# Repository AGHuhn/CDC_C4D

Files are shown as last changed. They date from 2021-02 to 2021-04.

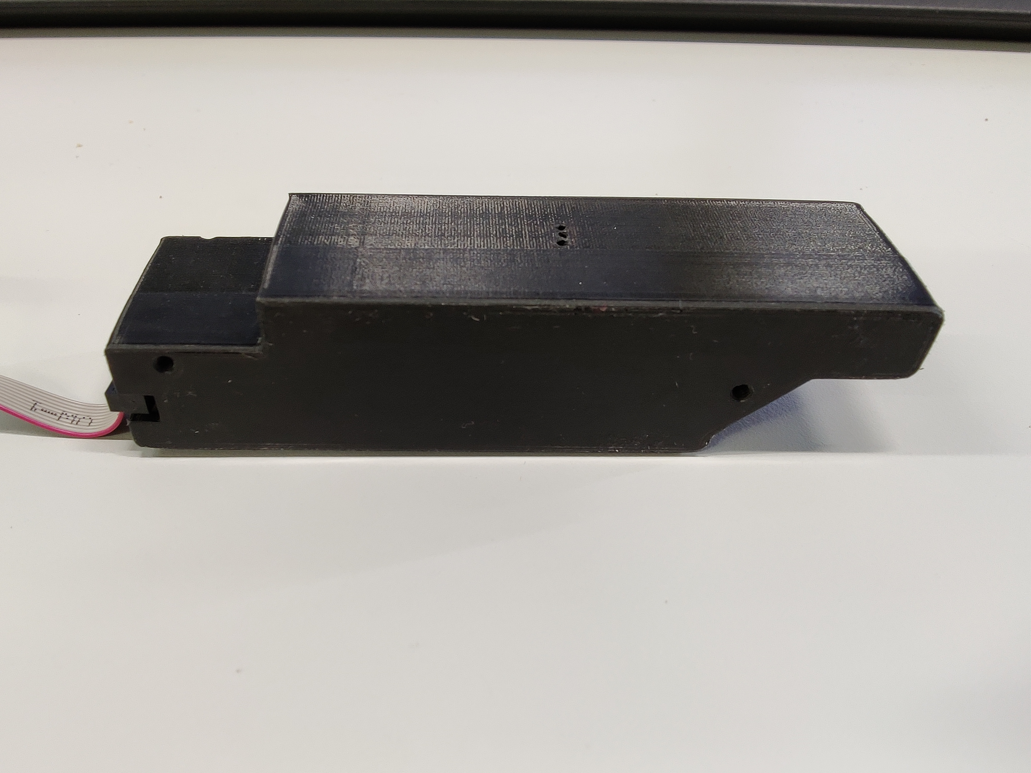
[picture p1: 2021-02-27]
Hardware/Case/IMG_20210218_153011.jpg

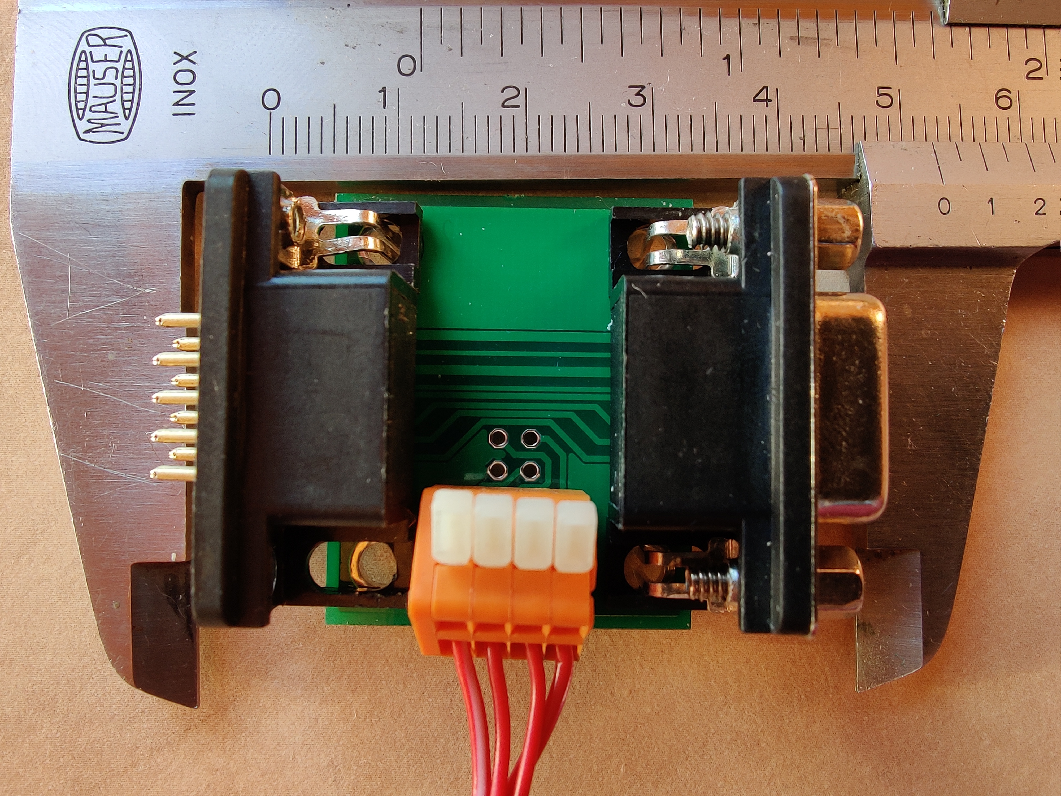
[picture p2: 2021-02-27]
Hardware/Trigger-Module/img_top.jpg

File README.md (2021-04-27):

# CDC_C4D

This repository provides building instructions and software to build and operate a capacitance-to-digital converter-based capacitively coupled contactless conductivity (C4D) for capillary electrophoresis.
The setup has the following features:
- performance comparable to other C4Ds
- automated measurements
- lightweight detection head
- wireless data transmission
- battery-powerd setups 
- multi-detector setups
- trigger module for popular commercial CE-Systems

All important information for building and operating is included in the CDCD_Manual.pdf 

The Folder [Hardware](https://github.com/AGHuhn/CDC_C4D/tree/main/Hardware) provides:
- A list of all needed parts
- Eagle Files for detection head (scheme and PCB design)
- Eagle Files for supply unit (scheme and PCB design)
- Eagle File for a Trigger Module for an Agilent CE 7100 (scheme and PCB design)
- Inventor Files for 3D printed case for supply unit of a detection unit

The Folder [Arduino](https://github.com/AGHuhn/CDC_C4D/tree/main/Arduino) contains the Firmware for the Arduino Nanos used

The Folder [Software](https://github.com/AGHuhn/CDC_C4D/tree/main/Software) contains a python 3 script with GUI (CDC_Viewer55.pyw) to acquire the data provides by the detectors 

Publication in [Electrophoresis](https://onlinelibrary.wiley.com/journal/15222683):
Graf, H.G., Rudisch, B.M., Manegold, J. and Huhn, C. (2021), Advancements in capacitance‐to‐digital converter‐based C4D technology for detection in capillary electrophoresis using amplified excitation voltages and comparison to classical and open‐source C4Ds. ELECTROPHORESIS. https://doi.org/10.1002/elps.202000394

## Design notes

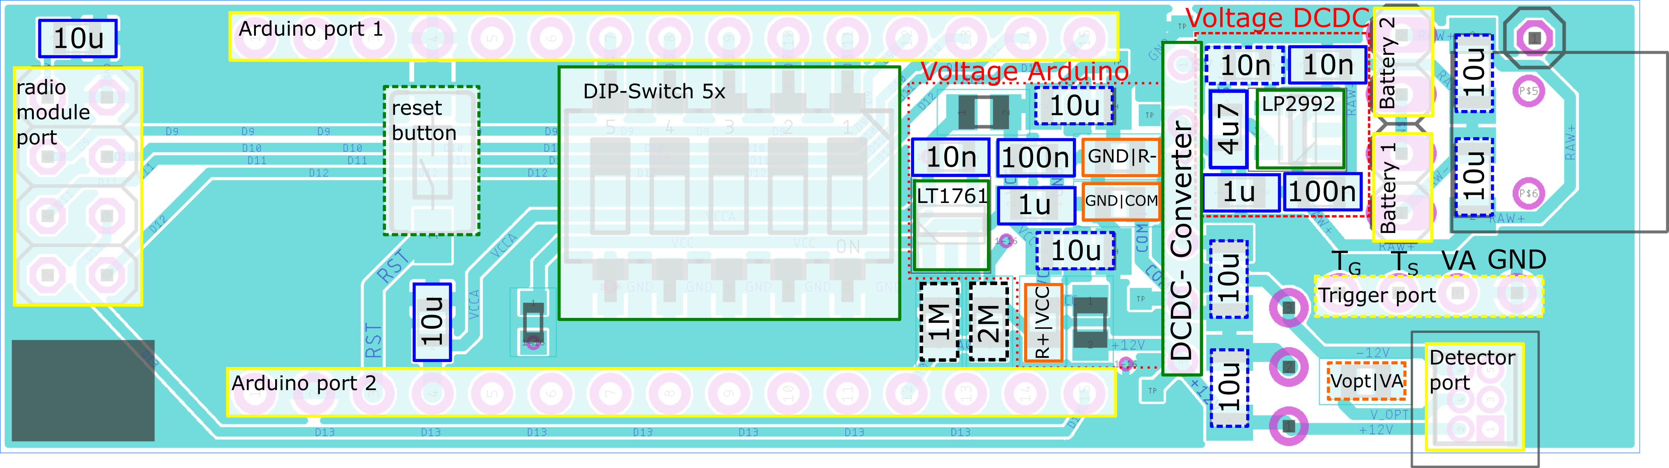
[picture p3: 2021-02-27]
Hardware/Supply_Unit/img/Top_nano_neu5_4b.png

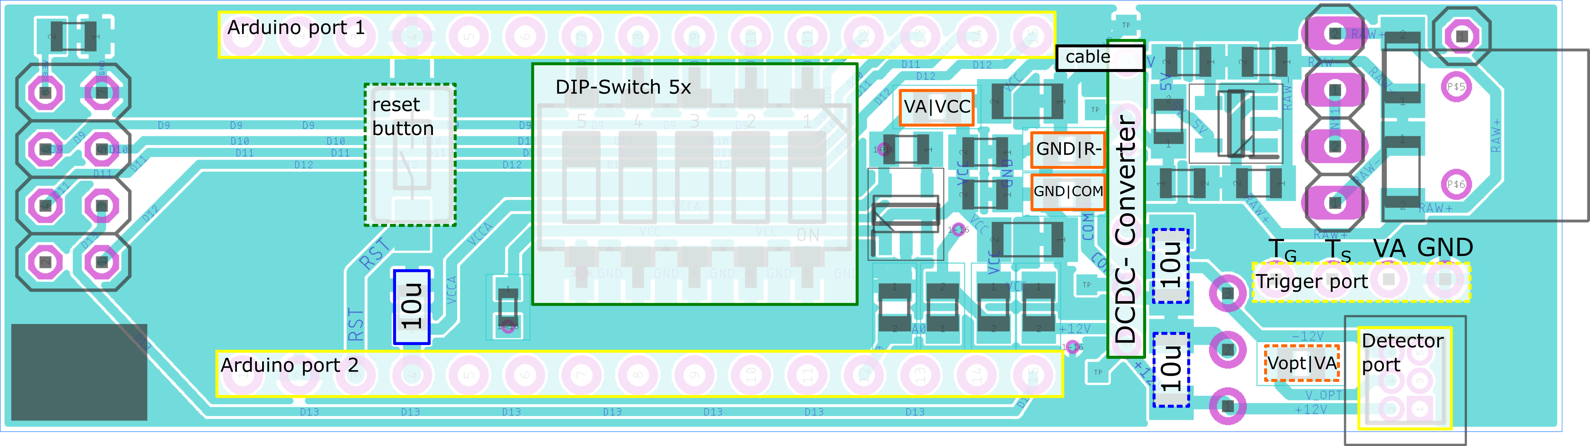
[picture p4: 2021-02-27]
Hardware/Supply_Unit/img/Top_nano_neu5_2_CA.png

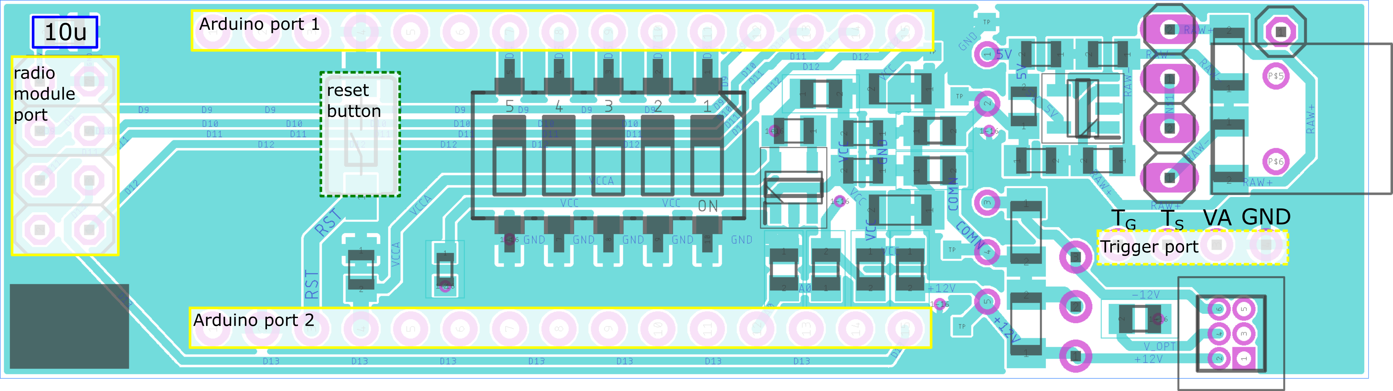
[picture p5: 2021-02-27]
Hardware/Supply_Unit/img/Top_nano_neu5_Master.png

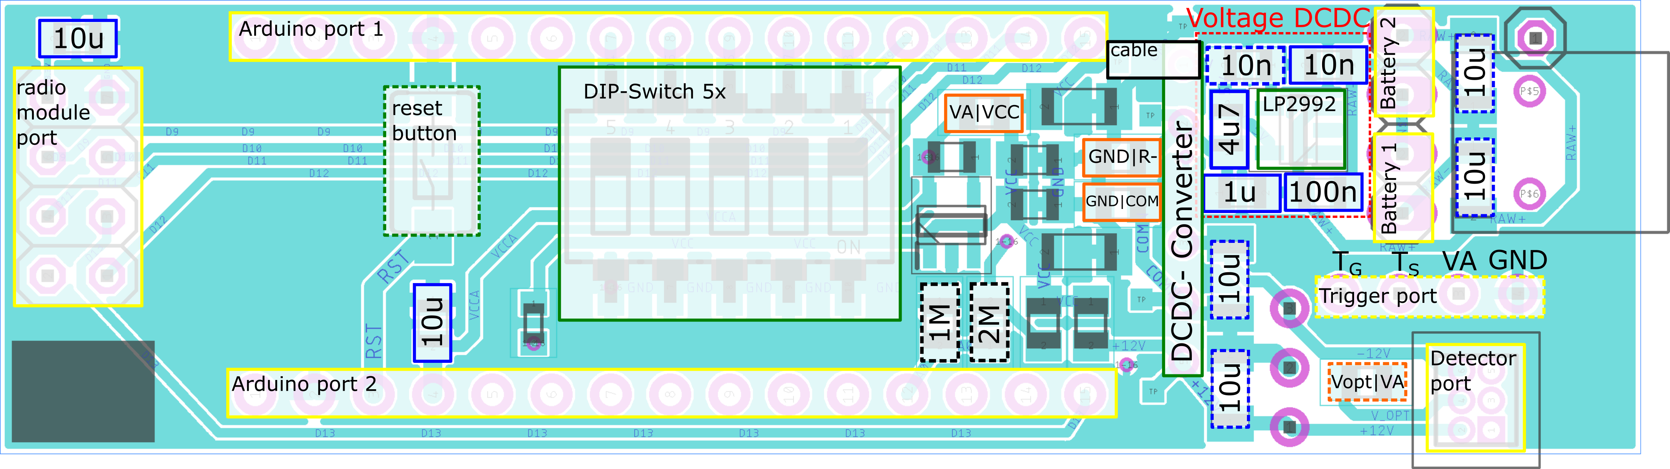
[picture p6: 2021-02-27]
Hardware/Supply_Unit/img/Top_nano_neu5_4d.png

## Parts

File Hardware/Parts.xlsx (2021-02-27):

Parts CDCD with amplifer and wireless data transmission
Typ | Value | Size | Number | Supplyer | Part Number | Link | Alternative
C | 10u | C0805K | 4 | Mouser | 810-C2012X5R1C106K-2 | https://www.mouser.de/ProductDetail/TDK/C2012X5R1C106K085AC?qs=sGAEpiMZZMs0AnBnWHyRQFzBYxg9rzNcukzxv1DZ6AE%3D
C | 1u | C0805K | 3 | Mouser | 963-TMK212B7105KG-T | https://www.mouser.de/ProductDetail/Taiyo-Yuden/TMK212B7105KG-T
C | 100n | C0805K | 4 | Mouser | 603-CC805ZRY5V9BB104 | https://www.mouser.de/ProductDetail/Yageo/CC0805ZRY5V9BB104
C | 10n | C0805K | 4 | Mouser | 710-885342207005 | https://www.mouser.de/ProductDetail/Wurth-Elektronik/885342207005
C | 4,7u | C0805K | 1 | Mouser | 791-0805B475K160CT | https://www.mouser.de/ProductDetail/walsin/0805b475k160ct/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 | https://www.mouser.de/ProductDetail/Murata-Electronics/GRM21BR71C475KE51L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
IC | LT1761ES5-5.0 | LDO | 2 | Mouser | 584-LT1761ES5-5TRPBF | https://www.mouser.de/ProductDetail/Analog-Devices-Linear-Technology/LT1761ES5-5TRPBF
IC | LP2992IM5-5.0 | LDO | 1 | Mouser | 926-2992IM5-5.0/NOPB | https://www.mouser.de/ProductDetail/texas-instruments/lp2992im5-50-nopb/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
IC | AD7745 | CDC | 1 | Mouser | 584-AD7745ARUZ | https://www.mouser.de/ProductDetail/Analog-Devices/AD7745ARUZ
IC | LT1360 | OpAMP | 1 | Mouser | 584-LT1360CS8#PBF | https://www.mouser.de/ProductDetail/Analog-Devices/LT1360CS8PBF?qs=ytflclh7QUVe1E6rQWPHsw%3D%3D
Pin | FTSH-103-01-F-D | 0,05'' 2*3 straight | 1 | Mouser | 200-FTSH10301FD | https://www.mouser.de/ProductDetail/Samtec/FTSH-103-01-F-D?qs=0lQeLiL1qyb7OHmlWV4egA%3D%3D
Pin | FTSH-103-01-F-D | 0,05'' 2*3 right-angled | 1 | Mouser | 200-FTSH10301FDRA | https://www.mouser.de/ProductDetail/samtec/ftsh-103-01-f-d-ra/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
Pin | PINHD-1X15-CB |  | 4 | Mouser | 992-15FX1-254MM | https://www.mouser.de/ProductDetail/Gravitech/15Fx1-254mm/?qs=Vxac6xGyzPnMG7UJxd5xkg%3D%3D
Pin | PINHD-2X4 |  | 2 | Mouser | 517-929975-01-04-RK | https://www.mouser.de/ProductDetail/3M-Electronic-Solutions-Division/929975-01-04-RK/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
R | 2M | R0805 | 1 | Mouser | 279-CPF0805B2M0E | https://www.mouser.de/ProductDetail/te-connectivity/cpf0805b2m0e/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
R | 1M | R0805 | 1 | Mouser | 756-PCF0805R1M0BI | https://www.mouser.de/ProductDetail/tt-electronics/pcf0805r-1m0bi/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
R | 10k | C0805K | 4 | Mouser | 667-ERJ-6ENF1002V | https://www.mouser.de/ProductDetail/Panasonic/ERJ-6ENF1002V
R | 51k | C0805K | 1 | Mouser | 667-ERJ-6ENF5102V | https://www.mouser.de/ProductDetail/Panasonic/ERJ-6ENF5102V
Switch | Dip 5x |  | 1 | Mouser | 490-DS04254205BK-SMT | https://www.mouser.de/ProductDetail/CUI-Devices/DS04-254-2-05BK-SMT?qs=wnTfsH77Xs6N9X5hXMPSow%3D%3D
Switch | Pushbutton |  | 1 | Mouser | 611-PTS636SM25SMTRLF | https://www.mouser.de/ProductDetail/CK/PTS636-SM25-SMTR-LFS?qs=vLWxofP3U2yIXR4iooxesw%3D%3D | https://www.ebay.de/itm/Microtaster-Mikroschalter-SMD-Taster-Schalter-Autoschlussel-DIY-Arduino-Projekt/173152639197
PCB terminal block |  | 4 Ports | 1 | Mouser | 651-1725672 | https://www.mouser.de/ProductDetail/Phoenix-Contact/1725672/?qs=Ul7CXFMnlWXX93F9bOV2pQ%3D%3D | https://www.reichelt.de/leiterplattenklemme-4-polig-rm-2-54-mm-dg308-2-54-4-p276216.html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
DCDC | 5V to +-12V | TMA_0512D | 1 | Reichelt | SIM2-0512D SIL7 | https://www.reichelt.de/dc-dc-wandler-am2d-z-2-w-12-v-2x-82-ma-sil-7-sim2-0512d-sil7-p35064.html?trstct=pol_0
Ribbon Wire |  | 10Pin | 1 | Mouser | 485-1675 | https://www.mouser.de/ProductDetail/Adafruit/1675
Battery connector Male |  |  | 2 | Mouser | 798-DF12P25DS05 | https://www.mouser.de/ProductDetail/Hirose-Connector/DF1-2P-25DS05/?qs=zOgoZG1CgI%252BnUcESyIRSRQ%3D%3D | https://www.reichelt.de/printstecker-einzelstecker-gewinkelt-2-polig-pss-254-2w-p14908.html
Battery connector Crimp Socket |  |  | 2 | Mouser | 798-DF12S25C | https://www.mouser.de/ProductDetail/Hirose-Connector/DF1-2S-25C/?qs=zOgoZG1CgI9qqq10oZzFAA%3D%3D | https://www.reichelt.de/kupplungs-leergehaeuse-crimptechnik-2-polig-psk-254-2w-p14857.html
Battery connector Crimp Contact |  |  | 4 | Mouser | 798-DF12428SC | https://www.mouser.de/ProductDetail/Hirose-Connector/DF1-2428SC/?qs=zOgoZG1CgI86igipCMsLYw%3D%3D | https://www.reichelt.de/crimpkontakte-fuer-psk-254--20-stueck-psk-kontakte-p14861.html
Copperfoil | 25M x 50 mm |  |  |  |  | https://www.ebay.de/itm/Kupferband-Kupferfolie-Klebeband-Selbstklebend-Abschirm-Schneckenband-25M-x-50mm/312729614140
heat shrink tubing | 1mm 2:1 |  |  |  |  | https://www.ebay.de/itm/Schrumpfschlauch-Schrumpfrate-2-1-verschiedene-Grosen-Meterware/173277941427
Arduino Nano |  |  | 2 | Makershop |  | https://www.makershop.de/kits/3-nano-v3/
5 x TP4056 Lipo Battery Charger |  |  | 1 | Makershop |  | https://www.makershop.de/module/sonstige/5-x-tp4056/
radio module | NRF24L01+ |  | 2 | Makershop |  | https://www.makershop.de/module/funk/5x-nrf24l01-2-4ghz-funkmodule-fuer-raspberry-pi-arduino/
Battery | 4000mAh |  | 2 |  |  | https://www.eremit.de/p/eremit-3-7v-4-000mah-high-cap-kroko
Trigger Module Agilent with pass trough
Connector (CE side) | D-Sub 9 Pin Connector Right Angle Male |  | 1 | Mouser | 523-L717SDE09P1ACH4R | https://www.mouser.de/ProductDetail/Amphenol-Commercial-Products/L717SDE09P1ACH4R/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
Connector (Trigger Cable side) | D-Sub 9 Pin Connector Right Angle Female |  | 1 | Mouser | 523-L77SDE09S1BH4F48 | https://www.mouser.de/ProductDetail/Amphenol-Commercial-Products/L77SDE09S1BCH4F48/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
Transistor NPN | BC847 |  | 2 | Mouser | 863-BC847BLT1G | https://www.mouser.de/ProductDetail/ON-Semiconductor/BC847BLT1G/?qs=vNc2DXHODiLAH81QlkcRzw%3D%3D
R | 10k | C0805K | 4 | Mouser | 667-ERJ-6ENF1002V | https://www.mouser.de/ProductDetail/Panasonic/ERJ-6ENF1002V
PCB terminal block |  | 4 Ports | 1 | Mouser | 651-1725672 | https://www.mouser.de/ProductDetail/Phoenix-Contact/1725672/?qs=Ul7CXFMnlWXX93F9bOV2pQ%3D%3D | https://www.reichelt.de/klemmleiste-rm-2-54-ffnungshebel-4-polig-wago-233-504-p31675.html

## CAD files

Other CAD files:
Hardware/Case/Case.ipt
Hardware/Case/Case_DIP.ipt

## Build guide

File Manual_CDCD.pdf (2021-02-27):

# Manual CDCD

## Content

## Introduction

This manual describes the use and setup of the CDC-based C⁴D (CDCD).
The CDCD provide 4 different types of use, which distinguish between the use of an amplifier on the detection head and the use of wireless data transmission. The configurations are summarized in the table below. Depending on the chosen configuration, the assembly of the hardware differs. All configurations can also be realized in a differential measurement mode setup.

Table 1: Configurations of CDCDs

Configuration | Wired data transmission (only one detector) | Wireless data transmission (up to 8 detectors, needs master device)
Without amplifier (needs link at the bottom of the detection head) | 1 | 3
With amplifier (needs fully equipped bottom of the detection head) | 2 | 4a-4d

### Setup for the first time a CDCD-set

1. Chose the desired configuration of the CDCDs according to Table 1.
2. Build according to the chapters “Building instructions for detection head” and “Building instructions for the supply unit” the required units.
3. Configure according to the chapter “Initial configuration” the CDCDs

### Use of preconfigured CDCDs

There are 4 different types of use, which distinguish between the use of an amplifier and the use of wireless data transmission, see Table 1.

Information: The Arduino Nanos must be preconfigured according to the section “Configuration” before use.
Wired data transmission
- Set switches 2,3,4 to ON; set the remaining switches to OFF
- Connect the Arduino’s USB port on the detection device to the PC
- Start the Software

Wireless data transmission, battery powered setups
- Connect Master device to PC
- On the detection unit: set switch 5 to “ON”, use switches 2-4 to set a unique id. Apply changes by pressing the momentary switch and wait until the Arduino restarts (see section “Coding”)
- Supply the detection unit by voltage (6 - 16V) at the ports mark ports in Figure 11.

## Additional Information

### Coding

The coding on the supply unit of the detection device must be unique, the coding can be changed at any time and must by applied by resetting the Arduino (disconnect the device from power or use one of the momentary switches).

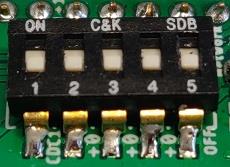
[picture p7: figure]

Figure 1:DIP-switches on the supply unit

Switches 2-4: Set the detection device ID according to: switch 2 adds 1 to CDC1 → CDC2; switch 3 adds 2, switch 4 adds 4.
All possibilities:
S 2 | S 3 | S 4 | Name | S 2 | S 3 | S 4 | Name
OFF | OFF | OFF | CDC1 | OFF | OFF | ON | CDC5
ON | OFF | OFF | CDC2 | ON | OFF | ON | CDC6
OFF | ON | OFF | CDC3 | OFF | ON | ON | CDC7
ON | ON | OFF | CDC4 | ON | ON | ON | CDC8
Switch 5: | OFF: Configuration mode; except switches 2 to 4 are set to ON → Usage without amplifier and wireless communication → CDC1 ON: wireless communication is activated

### Trigger

The trigger can be connected via a 4-pin terminal block. The trigger can be connected to any detection device or to the master. However, preferably on the master.

Two trigger mods are supported (change requires reprogramming)

- Prince Trigger-Mode (2 wire connection) (line 11: ce_ms = false)
| • The trigger TG is connected to GND via a switch of the CE. Every change in potential is evaluated as a trigger, the maximum pulse length must not exceed 4 s. Start and stop triggers take place at the same cable.
- Agilent Trigger-Mode (4 wire connection) (line 11: ce_ms = true)
| • Adapter board with 2x D-SUB 9 ports (male and female) and small parts is necessary

### Measurement mode

The detection head can also be equipped with a second pair of electrodes to allow a differential measurement setup. This requires also a change in the software for the Arduinos.

- Single-ended measurement mode (2 electrodes) (line 13: differential = false)
- Differential measurement mode (4 electrodes) (line 13: differential = true)

### LEDs:

Wireless data communication:

- LED on Master and detection device flash fast (approx. 10 Hz): Connection established successfully
- LED on Master and detection device flash slow: establishing connection
- LED on detection device flash slow: detection device searches for master
- LED on detection device is not flashing: detection head cannot be addressed (see: Known hardware problems)

## Software

### Required basic software

- Python 3.X along with PyQt5; matplotlib and pySerial
→ Anaconda Python 3.X : https://www.anaconda.com/distribution/
- System path “python” should be created in Windows (can be created automatically during installation, check the box next to “Add Anaconda to my PATH environment variable”)
- After installation of “Anaconda” add installation of “pySerial” via: Enter in command line (search for “cmd” in Windows): conda install -c anaconda pyserial confirm after some time by entering “y”. Installation is completed after the message “All requested Packages already installed”, close the window.
- To check the installation of the driver for the Arduino connect it to the PC. For troubleshooting have a look at: https://sparks.gogo.co.nz/ch340.html or https://www.makershop.de/ch340-341-usb-installieren/ (https://www.makershop.de/ch340-341-usb-installieren/) or search in the web for “CH340 driver”

### Measurement software

0. Connect the USB port of the Arduino of the master to the PC and supply the detection devices with power. When operating without radio: Connect the detection device’s Arduino to the PC.
1. Launch python software, pleas wait a moment until the UI appears.

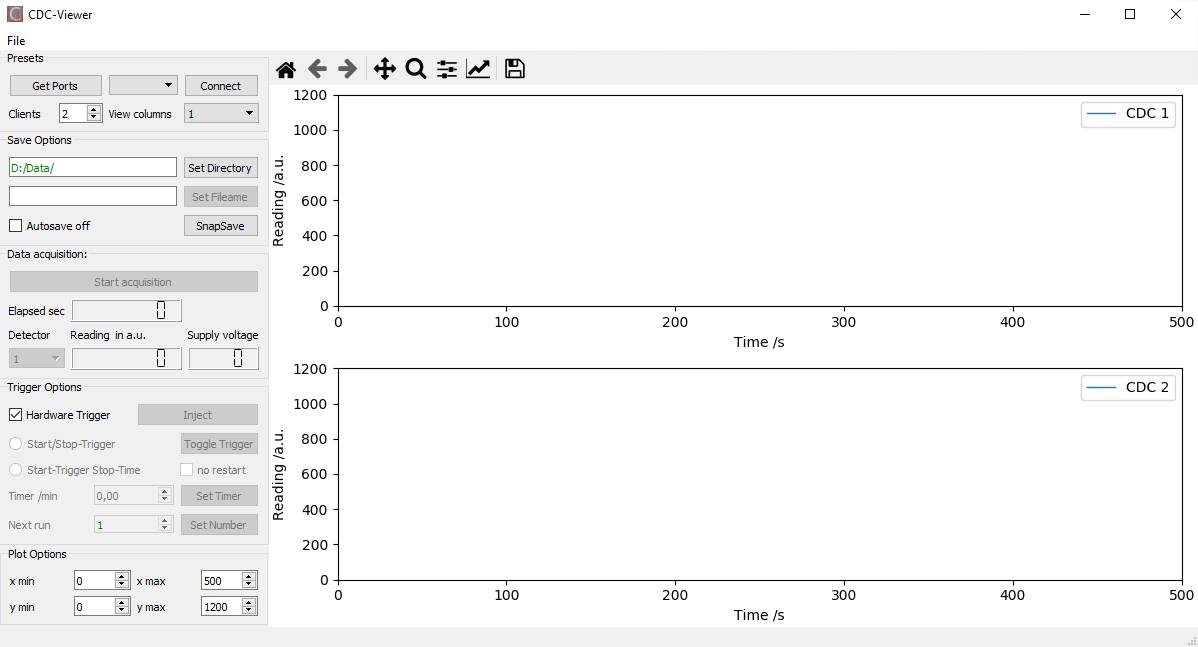
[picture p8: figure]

Figure 2. Software UI

2. Choose serial port of the Arduino and apply by clicking “Connect”, if port is not known, have a look at: Serial Monitor, COM-Port
3. Set number of detection devices (Clients), corresponds to the highest ID assigned via the DIP switches, and chose desired columns of plots, “0” disables live plot.
4. Save options: (Duplicates in the file name will result in the file being overwritten)
1. Autosave mode:
- Select Folder
- Enter any desired filename without file extension (min. 3 letters) apply by clicking “Set Filename”. Successful application is reported by green text color

Information: The chosen filename will be extended by _RX_DY whereas X increments the measurements (X is display in the box “Next run” / “Current run”) and Y denotes the number of the detection device (selected by the DIP switches)
2. Manual mode (Check “disable Autosave”)
- Save current plots via “SnapSave”
Information: The chosen filename will be extended by _DY, Y denotes the number of the detection device (selected by the DIP switches)
Information: “SnapSave” is also available in autosave mode
5. Data acquisition:
a) “Start acquisition” start the data acquisition
b) The combobox “Detector” allows to select a specific detector by its id.
c) “Reading in a.u.” displays the received value form the selected detector device in dependence of elapsed time since the last reset (“Elapsed sec”). “Supply voltage” displays the belonging voltage of the batteries.
6. Trigger Options:
a) In autosave mode, the “Inject” button can be used to start a recording manually. Afterwards, the same button, now labeled “Stop run”, stops the recording by clicking. This button works in any case, despite of a connected hardware trigger or the checkbox “Hardware-Trigger” is checked or unchecked.
See also section “Trigger”
b) Unchecking the checkbox “Hardware-Trigger” deactivates the trigger from hardware, the “Inject” / “Stop run” button are working anyway.
c) Start/Stop-Trigger: (preselected)
Start and stop of a measurement are defined by a trigger event at the beginning and the end of the measurement.
d) Start-Trigger Stop-Time:
Start via trigger event and stop after a predefined period
- Activation is only possible if the duration (“Timer /min”) is set to a value different form “0” and is applied by clicking “Set Time”.
- If “no restart” is checked, only the first trigger event is recognized. Only a single measurement with the set duration is recorded. Following triggers are disregarded.
e) Further options:
- “Current run” / “Next run” informs about the number of the next/current measurement, green text color. Adjustment is possible by changing the number. After applying with “Set Number”, the text color is green again.
- “Toggle Trigger” can be used in case of an error with the trigger. This button can be used to toggle whether the next trigger event is a start or a stop signal.
7. Plot:
Joint adaptation of the plot area in x and y direction of all diagrams.

### Known software issues

Information: All data is at any time recorded to a backup-directory which is in the temp folder in the root directory of the python script. The data is named: YYYY-mm-dd_HH-MM-SStemp_DX.csv
1.) Live-Plots stops working: no effect on measurement data if values in “Reading in a.u.” and / or “Elapsed sec” change.
2.) In case of errors regarding the matplotlib library: Enter in the Windows command line successively the following commands:
- pip uninstall matplotlib
- python -m pip install --upgrade pip
- pip install matplotlib

### Serial Monitor, COM-Port

Software: Arduino IDE (https://www.arduino.cc/en/Main/Software)

Accessing the serial monitor:

1. Connect the PC to the USB port on the Arduino Nano
2. Open Arduino IDE
3. Select the COM port at Tools >Ports> COM X
- If the port is not known: unplug the Arduino, display the port list, remind and close it. Plug in the Arduino and select the new entry in the port list. At the bottom right you should see Arduino Nano, ATmega328 (Old Bootloader) on COM X.
- If not: Select Tools > Board > Arduino Nano and select Tools > processor > ATmega328 (Old Bootloader)

Open the serial monitor (magnifying glass at the top right), select 19200 baud in the new window at the bottom right

## Configuration

### Initial configuration

In the initial configuration, the software is installed on the Arduinos and the detection sets are defined. The definition of the detection sets pairs all detection devices with a fixed master so that several sets can be used at the same time without crosstalk.

Preparatory steps
1. Make sure the Arduino IDE (https://www.arduino.cc/en/Main/Software) is installed
2. Copy the contents of the Arduino\libraries folder into the libraries folder of the working directory

of the Arduino software (%USERPROFILE%\Documents\Arduino)
The following folders are then contained in Arduino\libraries: RF24-master, SBNetwork-master
3. To check the installation of the driver for the Arduino connect the bare Arduino to the PC. For troubleshooting have a look at: https://sparks.gogo.co.nz/ch340.html or https://www.makershop.de/ch340-341-usb-installieren/ or search in the Web for „CH340 driver“
4. Define a set ID, this must be unique in the laboratory and must be entered later identically in all Arduinos of a detector set

Upload and configuration for the detection devices
Information: Start with the configuration of the detection device’s Arduinos. Only connect one Arduino on the PC during configuration.

Connect the PC to the USB port on the Arduino Nano with installed custom-made PCB (set all switches to OFF) and radio module
1. Open the file „CDC_Funk_MC_Multi_v19.ino“ at Arduino\CDC_Funk_MC_Multi_v19
2. Select the COM port at Tools > Ports > COM X
2.1. If the port is not known: unplug the Arduino, display the port list, remind and close it. Plug in the Arduino and select the new entry in the port list
3. At the bottom right you should see Arduino Nano, ATmega328 (Old Bootloader) on COM X. If not: Select Tools > Board > Arduino Nano and select Tools > processor > ATmega328 (Old Bootloader)
4. Check if line 10 contains the following: bool client = true; // Save bool for client/master
5. Set the desired trigger mode in line 11: for Prince: ce_ms = false; for Agilent: ce_ms = true
6. Set the desired measurement mode in line 13: for single-ended mode: differential = false, for differential measurement mode: differential = true
7. Upload CDC_Funk_MC_Multi_v19.ion with the arrow button „→„ or use Sketch > Upload; Success is confirmed by a message “Upload completed” below the sketch.
8. Set the detection device ID according to: switch 2 adds 1 to CDC1 → CDC2; switch 3 adds 2, switch 4 adds 4; switch 5 on ON activates the radio module.
All options:
S 2 | S 3 | S 4 | Name | S 2 | S 3 | S 4 | Name
OFF | OFF | OFF | CDC1 | OFF | OFF | ON | CDC5
ON | OFF | OFF | CDC2 | ON | OFF | ON | CDC6
OFF | ON | OFF | CDC3 | OFF | ON | ON | CDC7
ON | ON | OFF | CDC4 | ON | ON | ON | CDC8
Leave switch 5 on OFF for configuration
It is only necessary for the configuration of the CDC8 that a detector is plugged in and supplied with voltage.

9. Open the serial monitor (magnifying glass at the top right), select 19200 baud in the new window at the bottom right
The output should be:
Firmware:CDC_Funk_MC_Multi_v19
Hello at CDCX
SetupRadio is active
Enter 'N_X' to reset the wireless device and set it to client-master-set X Prince Trigger-Mode (2 wire connection)
CDCX
…
If X does not correspond to the set value: set the switches again and press the reset button on the Arduino.

For CDC8 a different output is displayed:

Firmware:CDC_Funk_MC_Multi_v19

Hello at CDC 8
Please make sure that a detector with power supply is connected to configure CDC8 or use a CDC in USB-only mode, in the latter case CDC is always named CDC1
„„„ Enter 'N_X' to reset the wireless device and set it to client-master-set X
Prince Trigger-Mode (2 wire connection)
Init...Get offset
…
done
CDC1;373;0;8396142
10. Configuration of the set ID „S“: Enter N_“S“ in the input field above the output in the serial monitor and confirm with „Enter“
The output should be: (here: „S“ = 9 and X = 2)
Erasing device configuration data...Done
SBNetwork Version 1.0.5
====================
Try to read device config from internal flash...Failed Creating new device config and stroing it to internal flash... Done
Device MAC = 0x5 0x4 0x4 0x9 0x2
Master MAC = 0x0 0x0 0x0 0x0 0x0
NetKey = 0
Initializing NRF24L01 transmitter...Done
Try to connect to master...Warning - Not paired to a master
11. Unplug the USB cable from the Arduino and set switch 5 to ON, radio is activated, connect the detection head

For additional detection devices it is in general possible to skip the steps 2 – 7. Doublecheck step 8 for each detection device to prevent identical IDs.

Upload and configuration for the master
Start analogously to steps 1-4 of section „Upload and configuration for the detection devices„:
5. Set line 10 for a master to: bool client = false; // Save bool for client/master
6. Set the desired trigger mode in line 11 : for Prince: ce_ms = false; for Agilent: ce_ms = true
7. Upload CDC_Funk_MC_Multi_v19.ion with the arrow button „→„ or use Sketch > Upload; Success is confirmed by a message „Upload completed“ below the sketch.
8. Open the serial monitor (magnifying glass at the top right), select 19200 baud in the new window at the bottom right
Output:
Firmware:CDC_Funk_MC_Multi_v19
Enter 'N_X' to reset the wireless device and set it to client-master-set X „„„ PRESS 'E' to handle the switch of adding new clients
Hello at CDC0
Prince Trigger-Mode (2 wire connection)
SBNetwork Version 1.0.5
====================

Try to read device config from internal flash...Done Device MAC = 0x5 0x4 0x4 0x8 0x0
Master MAC = 0x0 0x0 0x0 0x0 0x0
NetKey = 0
Masterstorage Slot 0 0x5 0x4 0x4 0x8 0x1 Masterstorage Slot 1 0x0 0x0 0x0 0x0 0x0 Masterstorage Slot 2 0x0 0x0 0x0 0x0 0x0 Masterstorage Slot 3 0x0 0x0 0x0 0x0 0x0 Masterstorage Slot 4 0x0 0x0 0x0 0x0 0x0 Masterstorage Slot 5 0x0 0x0 0x0 0x0 0x0 Masterstorage Slot 6 0x0 0x0 0x0 0x0 0x0 Masterstorage Slot 7 0x0 0x0 0x0 0x0 0x0 Masterstorage Slot 8 0x0 0x0 0x0 0x0 0x0
Masterstorage Slot 9 0x0 0x0 0x0 0x0 0x0
Initializing NRF24L01 transmitter...Done
9. Configuration of the set ID „S“: Enter N_“S“ in the input field above the output in the serial monitor and confirm with „Enter“
The output should be: (here: „S“ = 9)
Erasing device configuration data...Done
SBNetwork Version 1.0.5
====================

Try to read device config from internal flash...Failed Creating new device config and stroing it to internal flash... Done
Device MAC = 0x5 0x4 0x4 0x9 0x0
Master MAC = 0x0 0x0 0x0 0x0 0x0
NetKey = 0
Creating new Master Storage Masterstorage Slot 0 0x0 0x0 0x0 0x0 0x0 Masterstorage Slot 1 0x0 0x0 0x0 0x0 0x0 Masterstorage Slot 2 0x0 0x0 0x0 0x0 0x0 Masterstorage Slot 3 0x0 0x0 0x0 0x0 0x0 Masterstorage Slot 4 0x0 0x0 0x0 0x0 0x0 Masterstorage Slot 5 0x0 0x0 0x0 0x0 0x0 Masterstorage Slot 6 0x0 0x0 0x0 0x0 0x0 Masterstorage Slot 7 0x0 0x0 0x0 0x0 0x0 Masterstorage Slot 8 0x0 0x0 0x0 0x0 0x0 Masterstorage Slot 9 0x0 0x0 0x0 0x0 0x0
Initializing NRF24L01 transmitter...Done
„„„„„
Configuration:Master client-master-set-number:9 Device-Number: 0 „„„„„

10. Activation of the automatic detection device adding (all detection device that should not be connected to the master must not be in use): Enter „E“ in the input field above the output in the serial monitor and confirm with Enter
Output:
„„„„„
Activating AutomaticClientAdding
„„„„„
11. Power one detection device after the other. The master’s output displays:
Received 'SEARCH_MASTER'. Send MasterACK...Done
Received 'PAIRING_REQUEST'. Send PairingACK... Done Storing new MAC to MasterStorage... Done CDC1;8388608;0;13195058
…
Received 'SEARCH_MASTER'. Send MasterACK...Done Received 'PAIRING_REQUEST'. Send PairingACK... Done Storing new MAC to MasterStorage... Done
CDC2;8388608;0;13030720
etc.
12. Enter „E“ in the input field above the output in the serial monitor and confirm with Enter to disable the automatic detection device adding, after adding all detector devices.
Output:
„„„„„
Deactivating AutomaticClientAdding
„„„„„
13. Disconnect the master from the USB cable
14. Configuration is finished

### Follow-up configuration – detection device

Note: Only connect one Arduino on the PC during configuration.

1. Connect the PC to the USB port on the Arduino Nano with installed custom-made PCB (switch 4 on OFF) and radio module
2. Open Arduino IDE
3. Select the COM port at Tools > Ports > COM X
- If the port is not known: unplug the Arduino, display the port list, remind and close it. Plug in the Arduino and select the new entry in the port list
4. Set the detection device ID according to: switch 2 adds 1 to CDC1 → CDC2; switch 3 adds 2, switch 4 adds 4; switch 5 on ON activates the radio module.

All options:
S 2 | S 3 | S 4 | Name | S 2 | S 3 | S 4 | Name
OFF | OFF | OFF | CDC1 | OFF | OFF | ON | CDC5
ON | OFF | OFF | CDC2 | ON | OFF | ON | CDC6
OFF | ON | OFF | CDC3 | OFF | ON | ON | CDC7
ON | ON | OFF | CDC4 | ON | ON | ON | CDC8
Leave switch 5 on OFF for configuration

It is only necessary for the configuration of the CDC8 that a detector is plugged in and supplied with voltage.

5. Open the serial monitor (magnifying glass at the top right), select 19200 baud in the new window at the bottom right
The output should be:
Hello at Number: X
„„„ PRESS 'N_4' to reset the wireless device and set it to client-master-set 4,
if no confirmation is displayed, retry it with disabled Network
Init...done
CDCX
If X does not correspond to the set value: set the switches again and press the reset button.
6. Configuration of the set ID *S*: Enter N_*S* in the input field above the output in the serial monitor and confirm with “Enter”
The output should be: (here: *S* = 9 and X = 2)
Erasing device configuration data...Done
SBNetwork Version 1.0.5
====================
Try to read device config from internal flash...Failed Creating new device config and stroing it to internal flash... Done
Device MAC = 0x5 0x4 0x4 0x9 0x2
Master MAC = 0x0 0x0 0x0 0x0 0x0
NetKey = 0
Initializing NRF24L01 transmitter...Done
Try to connect to master...Warning - Not paired to a master
7. Unplug the USB cable from the Arduino and set switch 5 to ON, radio is activated, connect the detection head

### Reset of the master device

Note: all previously trained detector devices will be deleted
Procedure analogous to steps 1 - 3 of the “Follow-up configuration – detection device”
4. All coding switches are set to OFF or are not installed.
5. Open the serial monitor (magnifying glass at the top right), select 19200 baud in the new window at the bottom right
Output:
Firmware:CDC_Funk_MC_Multi_v19
„„„ Enter 'N_X' to reset the wireless device and set it to client-master-set X
„„„ PRESS 'E' to handle the switch of adding new clients
Hello at CDC 0
Prince Trigger-Mode (2 wire connection)
SBNetwork Version 1.0.5
====================

Try to read device config from internal flash...Done Device MAC = 0x5 0x4 0x4 0x9 0x0
Master MAC = 0x0 0x0 0x0 0x0 0x0
NetKey = 0
Masterstorage Slot 0 0x5 0x4 0x4 0x8 0x1 Masterstorage Slot 1 0x0 0x0 0x0 0x0 0x0 Masterstorage Slot 2 0x0 0x0 0x0 0x0 0x0 Masterstorage Slot 3 0x0 0x0 0x0 0x0 0x0 Masterstorage Slot 4 0x0 0x0 0x0 0x0 0x0 Masterstorage Slot 5 0x0 0x0 0x0 0x0 0x0 Masterstorage Slot 6 0x0 0x0 0x0 0x0 0x0 Masterstorage Slot 7 0x0 0x0 0x0 0x0 0x0 Masterstorage Slot 8 0x0 0x0 0x0 0x0 0x0 Masterstorage Slot 9 0x0 0x0 0x0 0x0 0x0 Initializing NRF24L01 transmitter...Done CDC1;556;0;8396837

6. Configuration of the set number *S*: Enter N_*S* in the input field above the output in the serial monitor and confirm with “Enter”
Output: (here: *S* = 9)
Output:
Erasing device configuration data...Done
SBNetwork Version 1.0.5
====================

Try to read device config from internal flash...Failed Creating new device config and stroing it to internal flash... Done
Device MAC = 0x5 0x4 0x4 0x9 0x0
Master MAC = 0x0 0x0 0x0 0x0 0x0
NetKey = 0
Creating new Master Storage Masterstorage Slot 0 0x0 0x0 0x0 0x0 0x0 Masterstorage Slot 1 0x0 0x0 0x0 0x0 0x0 Masterstorage Slot 2 0x0 0x0 0x0 0x0 0x0 Masterstorage Slot 3 0x0 0x0 0x0 0x0 0x0 Masterstorage Slot 4 0x0 0x0 0x0 0x0 0x0 Masterstorage Slot 5 0x0 0x0 0x0 0x0 0x0 Masterstorage Slot 6 0x0 0x0 0x0 0x0 0x0 Masterstorage Slot 7 0x0 0x0 0x0 0x0 0x0 Masterstorage Slot 8 0x0 0x0 0x0 0x0 0x0 Masterstorage Slot 9 0x0 0x0 0x0 0x0 0x0
Initializing NRF24L01 transmitter...Done
„„„„„
Configuration:Master client-master-set-number:9 Device-Number: 0
„„„„„
7. Activation of the automatic detection device adding (all detection device that should not be connected to the master must not be in use): Enter “E” in the input field above the output in the serial monitor and confirm with Enter
Output:
„„„„„
Activating AutomaticClientAdding
„„„„„
8. Power one detection device after the other. The master’s output displays:
Received 'SEARCH_MASTER'. Send MasterACK...Done
Received 'PAIRING_REQUEST'. Send PairingACK... Done Storing new MAC to MasterStorage... Done CDC1;8388608;0;13195058
…
Received 'SEARCH_MASTER'. Send MasterACK...Done Received 'PAIRING_REQUEST'. Send PairingACK... Done Storing new MAC to MasterStorage... Done
CDC2;8388608;0;13030720
etc.
9. Enter “E” in the input field above the output in the serial monitor and confirm with Enter to disable the automatic detection device adding, after adding all detector devices.
Output:
„„„„„
Deactivating AutomaticClientAdding
„„„„„
10. Disconnect the master from the USB cable
11. Configuration is finished

### Add additional detection devices to a master

Prepare the detection device with the same set ID as all other detection device according to the item “Upload and configuration for the detection devices” or “Follow-up configuration – detection device”.

Then continue according to “Reset of the master” WITHOUT performing step 6

Note: Another client can be added in while other clients are in operation

## Hardware

A CDCD-set can consist out of two different devices which in turn consist of individual units: 1.) Detection device:
- detection head
- supply unit
2.) Master device (only needed with wireless data transmission)
A CDCD-set consist of a master device and up to 8 detection devices.

The different hardware configurations of the detection head and the supply unit are described in the chapters “Building instructions for detection head” and “Building instructions for the supply unit”

### Known hardware problems

Error pattern | Solution
Data is received very rarely (frequency below 10 Hz) | Try another position of the master or detection device supply unit
The Arduino's pins get warm | Check whether there is no short circuit (start with: 3V3 against GND on the Arduino if there is a connection, remove the radio module and check again. If there is no more short circuit: replace the radio module)

### Building instructions for detection head

1. Detach of the 4 mini-PCBs on the right of Figure 3 the result is shown in Figure 4.
A | B

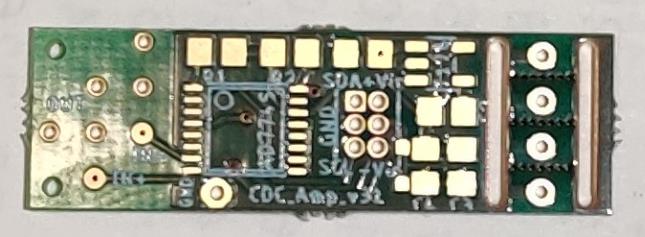
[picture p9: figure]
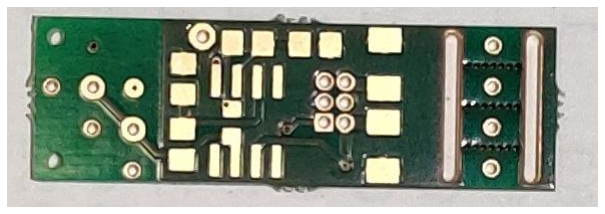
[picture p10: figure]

Figure 3: Images of the (A) top and (B) bottom of the entire detection head’s PCB.
A | B

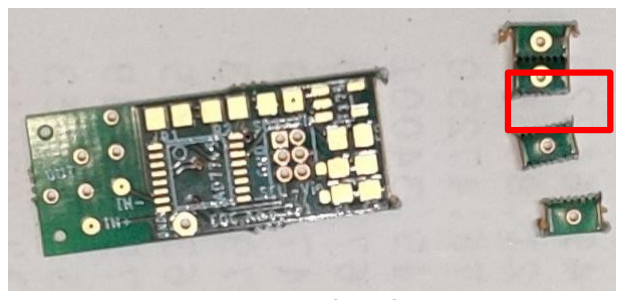
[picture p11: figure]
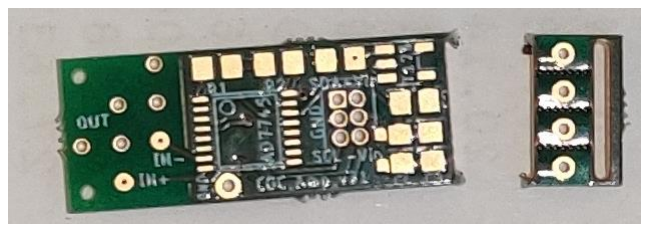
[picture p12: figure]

Figure 4: Images of the detection head circuit board with detached mini circuit boards. One of the further used mini PCBs is outlined in red.

2. Solder the required components according to Table 2 onto the larger PCB. The schematics is displayed in Figure 5. The equipped top and bottom of the detection head’s PCB with and without installed amplifier can be found in Figure 6.
A | B

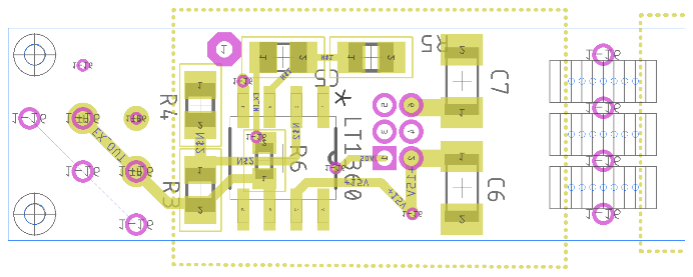
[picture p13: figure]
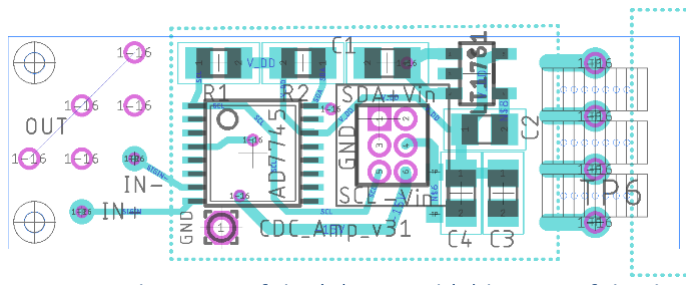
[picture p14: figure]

Figure 5: Schematics of the (A) top and (B) bottom of the detection head’s PCB.

Table 2: Components of the detection head
Top:
Part | Value | Package
AD7745 | AD7745 | TSSOP16
LT1761-5 | LT1761 | SOT23-5
C1 | 1u | C0805
C2 | 10n | C0805
C3 | 10u | C0805
C4 | 100n | C0805
JP1 | FTSH-103-01-F-D

Bottom:
Configuration 1 and 3 (no Amplifier): solder pads of R6 together Configuration 2 and 4 (with amplifier):
Part | Value | Package
LT1360 | LT1360CS8PBF
C5 | 100n | C0805
R3 | 51k | R0805
R4 | 10k | R0805
R5 | 10k | R0805
C6 | reserved | C1206K
C7 | reserved | C1206K
Information: The head could also be supplied by the 5 V line of the Arduino, if the jumper Vopt|VA on the supply unit of the detection unit is connected and the test pad next to the upper pad of C4 is linked, see Figure 5

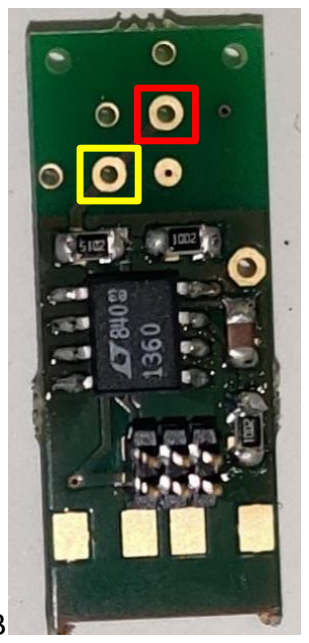
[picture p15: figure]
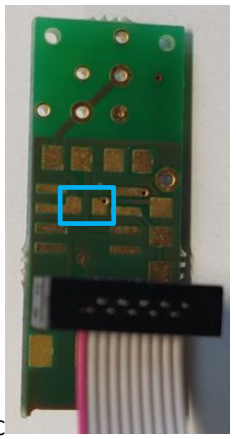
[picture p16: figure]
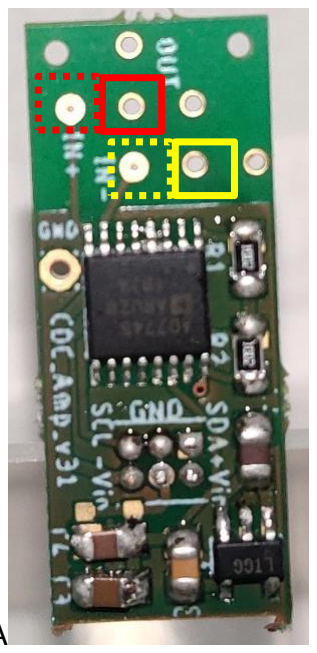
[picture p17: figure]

A | B | C
Figure 6: Images of the equipped (A) top and (B+C) bottom of the detection head’s PCB with (B) and without
(C) amplifier (link between the two pads in the blue box is missing)
3. Prepare the cannula segments by cutting a cannula to the desired length. Inset a capillary during cutting. Use cannulas with inner diameter of 0.4 mm (outer diameter 0.6, Gauge 23).

Figure 7: A pair of cannulas cut to a length of 10 mm each on a 360 µm outer diameter capillary.

4. Solder one cannula segment to the PCB of the detection head (outlined in red in Figure 6) and one to the mini-PCB. The soldering joint must be on the side with the larger soldering pad this is also the side where the electrode sticks out. The other side of the electrode should be at the same level as the PCB. The result is shown in Figure 8. For setups in differential measurement mode, a second pair of electrodes are mounted in the same way but to the yellow outlined boxes in Figure 6

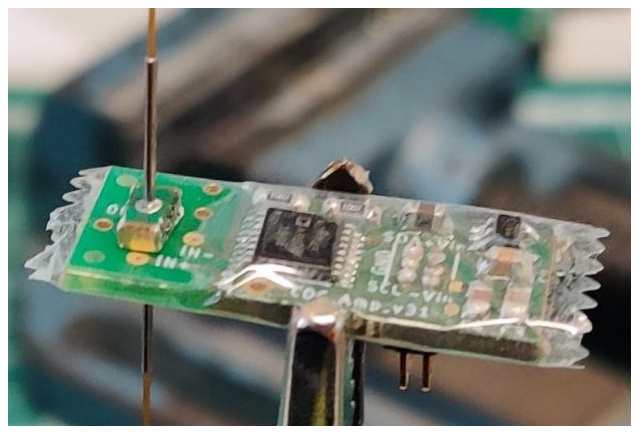
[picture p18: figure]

A | B

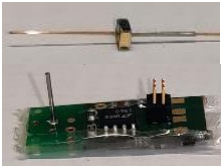
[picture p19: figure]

Figure 8: (A) mini-PCB and large PCB equipped with electrodes. The larger PCB is wrapped in transparent adhesive tape to prevent short circuits. The mini-PCB with an electrode is equipped with a capillary. (B) Both PCBs just before soldering them together (golden side of the mini-PCB and the pad next to the label IN+)

5. After wrapping the larger PCB in transparent adhesive tape, punch a hole with a needle in the tape, where the capillary must pass it.

6. Solder the mini-PCB to the larger PCB, it is important to solder the golden side connected electrically to the electrode of the mini-PCB to the pad connected to the input of the CDC-IC. The mounting pad IN+ is dotted outlined in red in Figure 6. The tape covering the mounting pad has not to be removed since it will melt during the soldering process anyway. Insert a capillary trough both electrodes while soldering.
7. Use heat shrink tubing to cover the electrodes and carefully wrap the PCBs with a layer of transparent adhesive tape. Keep the tape away from the golden side of the large PCB.
A | B

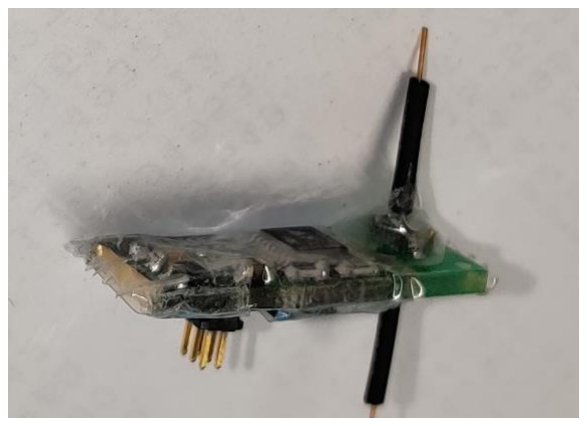
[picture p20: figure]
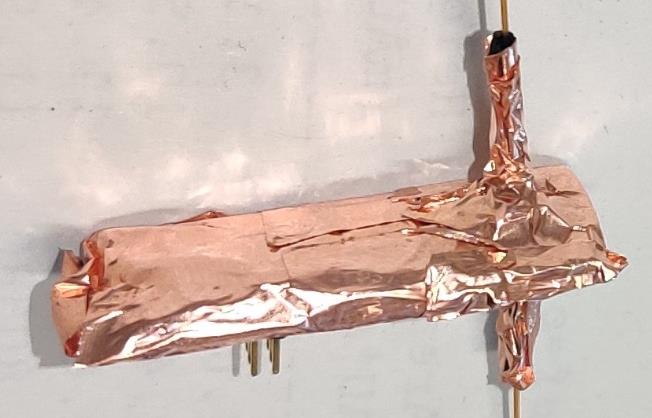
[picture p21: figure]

Figure 9: detection head (A) before and (B) after wrapping with adhesive copper foil

8. Wrap the detector carefully with adhesive copper foil, solder it to the golden side of the large PCB to connect it to ground. If necessary, solder the individual layers of the outer copper layer together to ensure proper electrical connection among themselves.

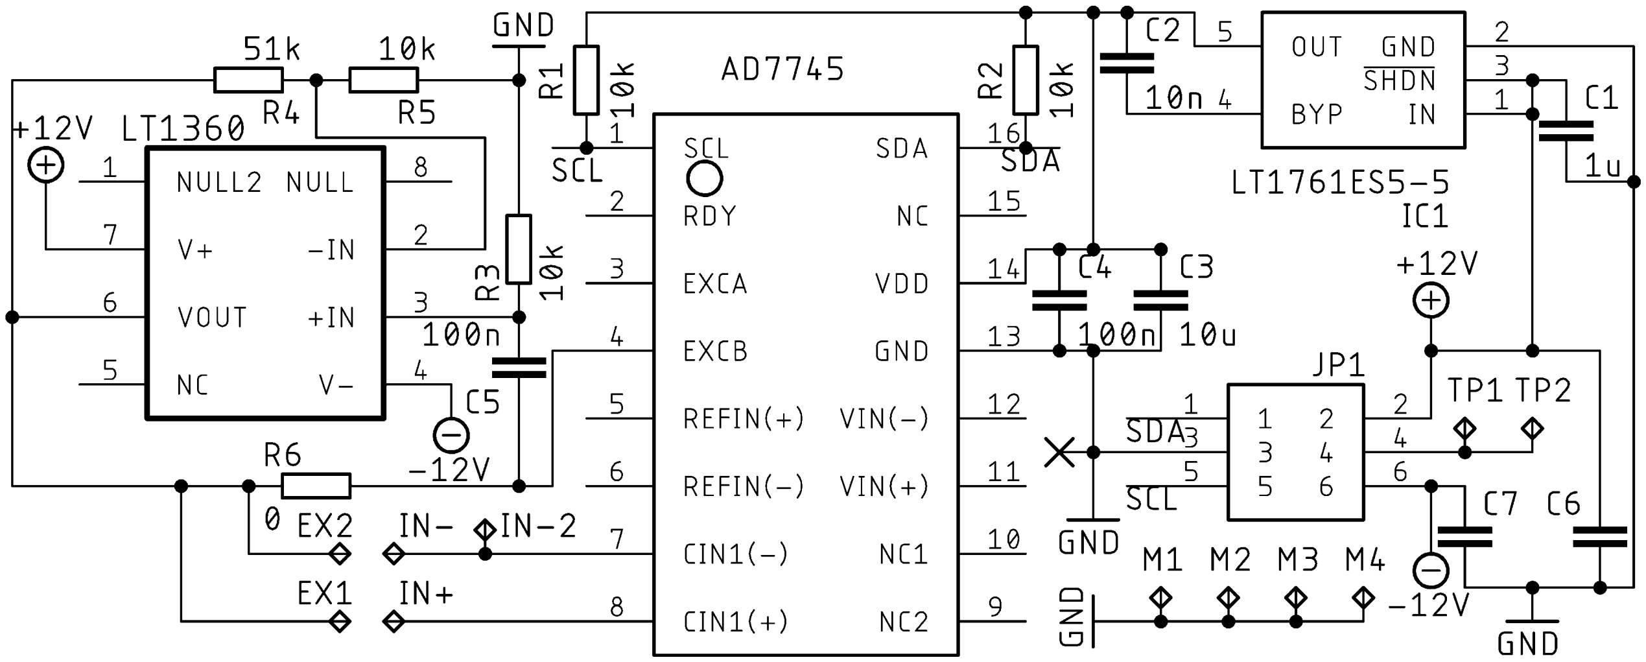
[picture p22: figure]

Figure 10. Schematic diagram of the detection head’s circuit. Capacitors without values are reserved. Resistor R6 is a jumper.

### Building instructions for the supply unit

The supply unit consists except for a PCB described below out of an Arduino Nano and a NRF24L01+ radio module. It provides pins for the connection to the detection head as well as an optional PCB terminal block for a trigger signal with an additional 5 V output. The DIP-switches on the supply unit are used for configuration.

The necessary components on the supply unit depending on the desired configuration can be taken from the figures in this section.

Fully annotated PCB of a supply unit:

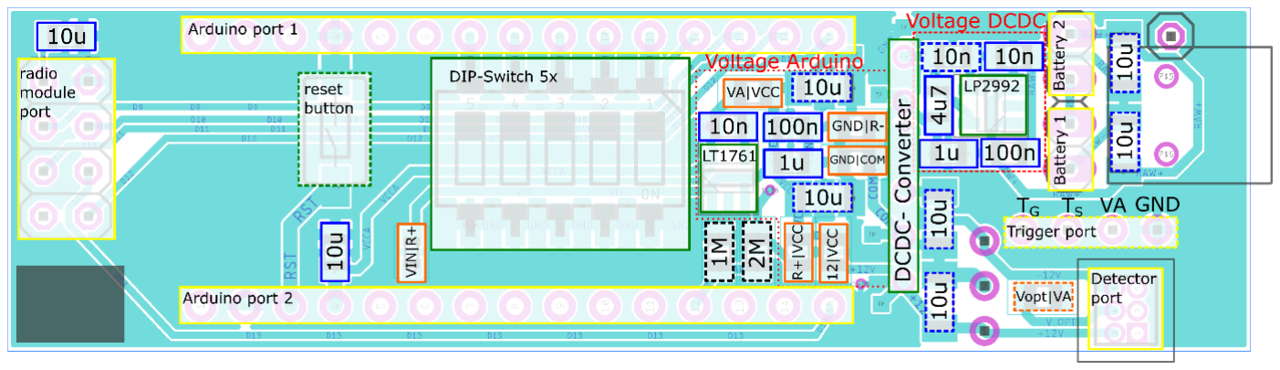
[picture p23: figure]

Color code: yellow: connectors; green: IC, buttons, and switches; black: resistors; blue: capacitors; orange: jumpers

Information: the dashed outlined 1 MΩ and 2 MΩ resistors are optional and allow tracking of the battery voltage.

Information: the dashed outlined reset button and the trigger port PCB block terminal are optional as well as all dashed outlined 10 µF capacitors.

Information: the dashed outlined 10 nF capacitor in Voltage DCDC is necessary if LP2992-5 is replaced by an LT1761-5. Further, the solid outlined 10 nF capacitor must not be installed and the 4.7 µF capacitor must be replaced by a 10 µF capacitor.

Information: The detection head can also be supplied directly from the 5 V supplying the Arduino by linking the dashed outlined jumper Vopt|VA

Supply unit of a master device

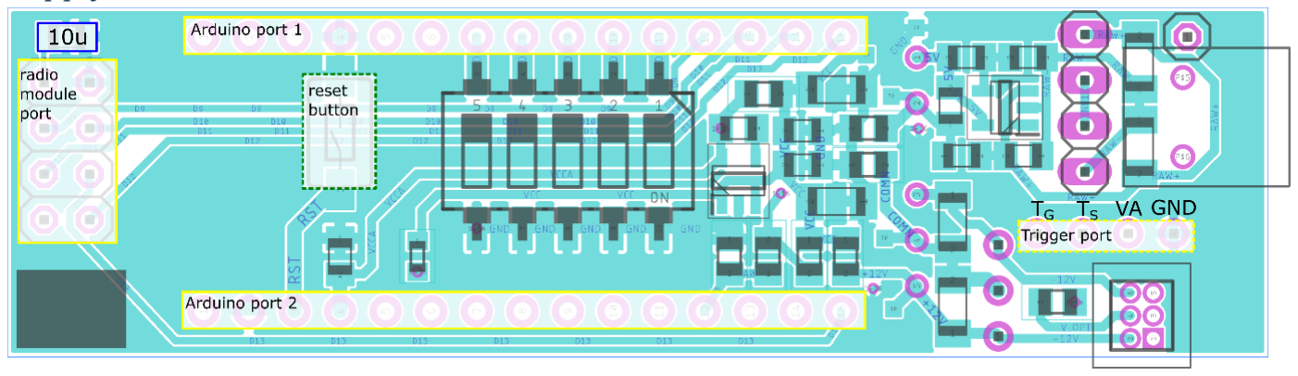
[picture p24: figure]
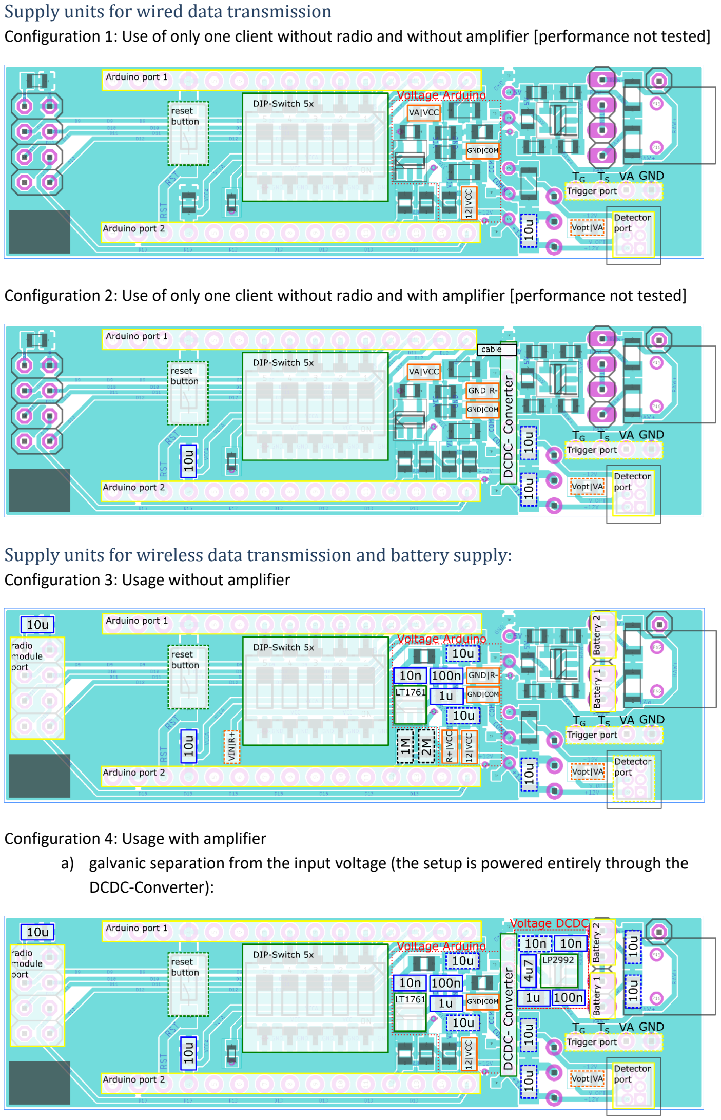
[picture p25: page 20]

Supply units for wired data transmission
Configuration 1: Use of only one client without radio and without amplifier [performance not tested]

Configuration 2: Use of only one client without radio and with amplifier [performance not tested]

Supply units for wireless data transmission and battery supply: Configuration 3: Usage without amplifier

Configuration 4: Usage with amplifier
a) galvanic separation from the input voltage (the setup is powered entirely through the DCDC-Converter):

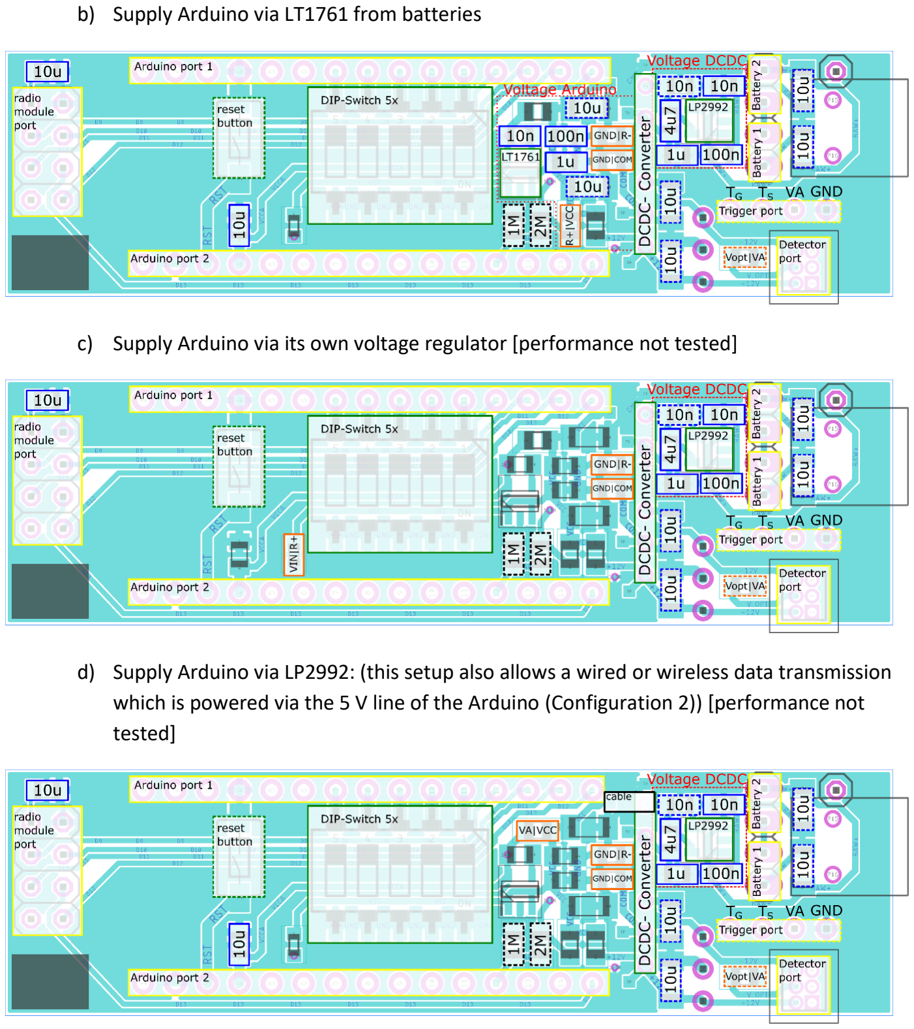
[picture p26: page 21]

b) Supply Arduino via LT1761 from batteries
c) Supply Arduino via its own voltage regulator [performance not tested]
d) Supply Arduino via LP2992: (this setup also allows a wired or wireless data transmission which is powered via the 5 V line of the Arduino (Configuration 2)) [performance not tested]

Images of a supply unit in configuration 4d, Arduino is supplied via LP2992

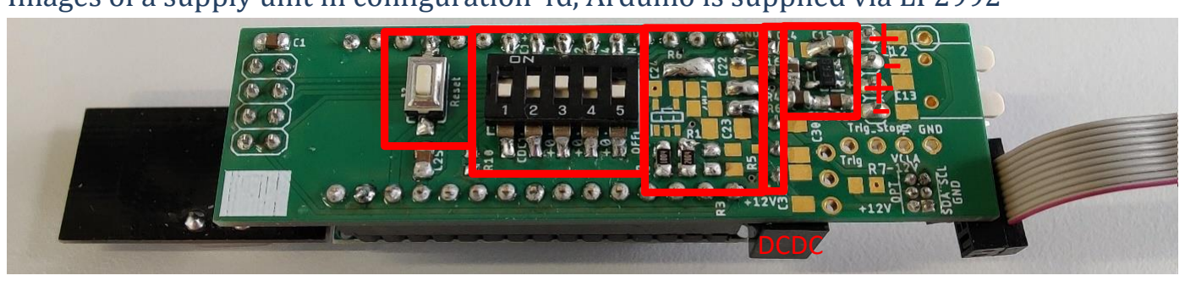
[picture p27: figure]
DCDC

Figure 11. Supply unit of detection device – top
Left: Reset-Taster
Center left: DIP-switch. switch 2-4 to configure id; switch 5: enable radio module (switch on OFF)
Center: Area for voltage regulator for Arduino and resistors (with values 1M, 2M), here Arduino powered directly from LP2992 (VA|VCC are linked and a wire is installed between the test pad next to the print VCC and Pin 1 of the DCDC; see top right corner)
Center right: DCDC solder pads
Right: Area for voltage regulator for DCDC-converter
“+” and “-” denote the polarities of two in series connected ports for the batteries (3.7 V each)

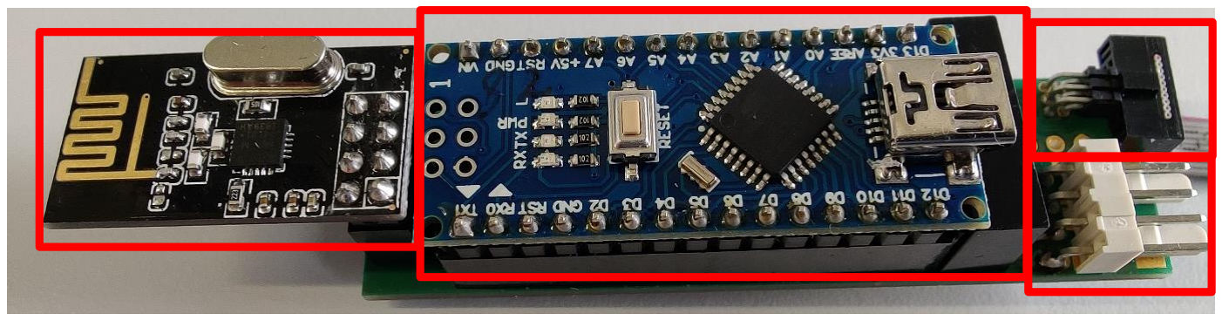
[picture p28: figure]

Figure 12. Supply unit of detection device – bottom, equipped Left: radio module Center: Arduino Nano
Top right: connector for 10-core ribbon cable to detection head
Bottom right: two connectors to attach the necessary pair of batteries (2x 3.7 V)

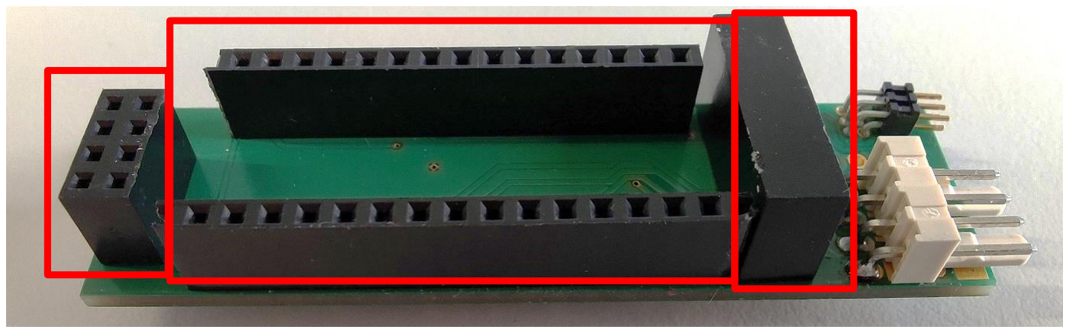
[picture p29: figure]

Figure 13. Supply unit of detection device – bottom Left: 2x4 socket for radio module
Center: 2x 1x15 socket for Arduino Nano
Right: DCDC-Converter

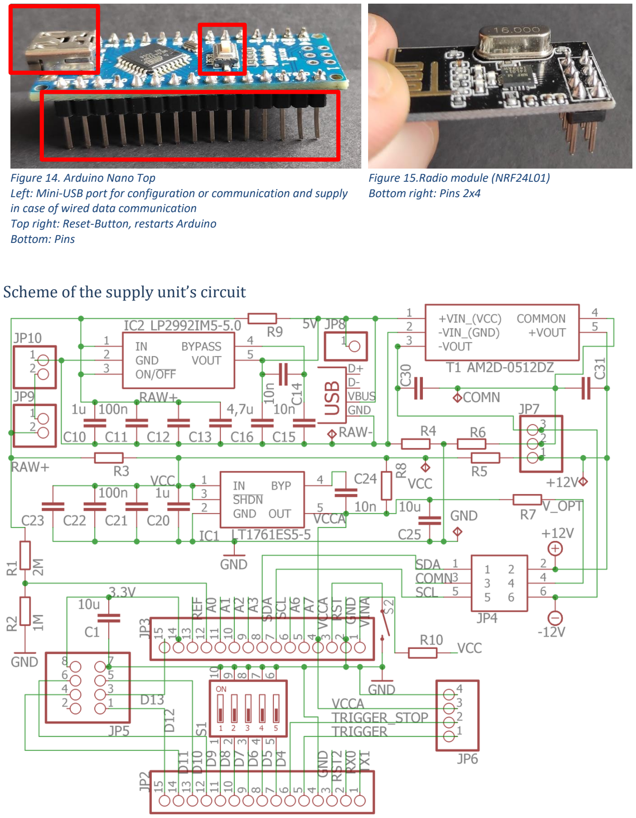
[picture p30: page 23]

Figure 14. Arduino Nano Top
Left: Mini-USB port for configuration or communication and supply in case of wired data communication
Top right: Reset-Button, restarts Arduino
Bottom: Pins

Figure 15.Radio module (NRF24L01) Bottom right: Pins 2x4

Scheme of the supply unit’s circuit

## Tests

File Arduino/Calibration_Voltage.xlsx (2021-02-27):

Analog | Voltage
557 | 8.112
546 | 7.972
534 | 7.805
525 | 7.674
513 | 7.497
506 | 7.387
499 | 7.286
496 | 7.249
493 | 7.201
490 | 7.154
486 | 7.098
483 | 7.053
478 | 6.988

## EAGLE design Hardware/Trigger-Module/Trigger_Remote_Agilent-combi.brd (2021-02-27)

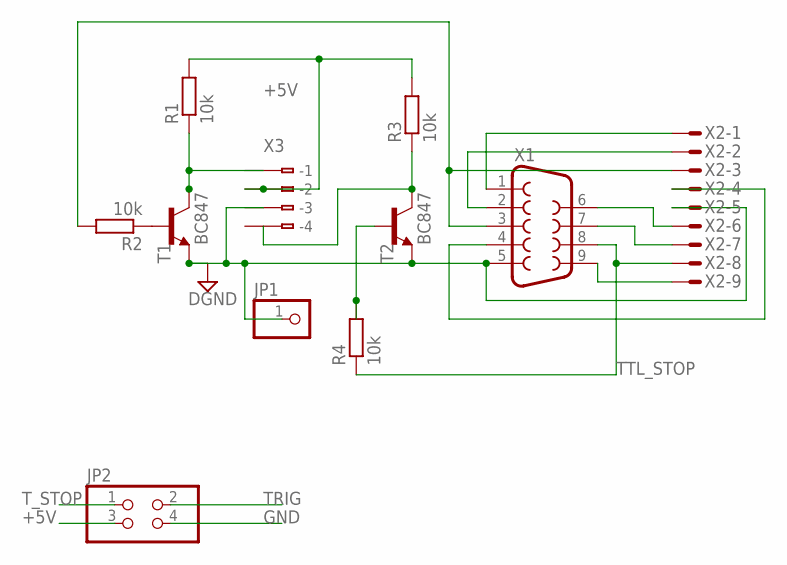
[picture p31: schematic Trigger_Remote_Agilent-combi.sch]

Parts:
JP1: PINHD-1X1; 1X01
JP2: PINHD-2X2; 2X02
R1, R2, R3, R4: 10k; M0805
T1, T2: BC847; SOT23
X1: F09HP
X2: M09HPS; M09HP
X3: 233-504

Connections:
+5V: JP2.3, R1.2, R3.2, X3.A2 (-2), X3.B2 (B-2)
GND: JP1.1, JP2.4, T1.2 (E), T2.2 (E), X1.5, X2.5, X3.A3 (-3)
unnamed: X1.1, X2.1
unnamed: X1.2, X2.2
unnamed: X1.4, X2.4
unnamed: R2.1, T1.1 (B)
unnamed: X1.9, X2.9
unnamed: X1.7, X2.7
unnamed: X1.6, X2.6
unnamed: R4.2, T2.1 (B)
TRIG: JP2.2, R1.1, T1.3 (C), X3.A1 (-1)
TTLSTART: R2.2, X1.3, X2.3
TTL_STOP: R4.1, X1.8, X2.8
T_STOP: JP2.1, R3.1, T2.3 (C), X3.A4 (-4)

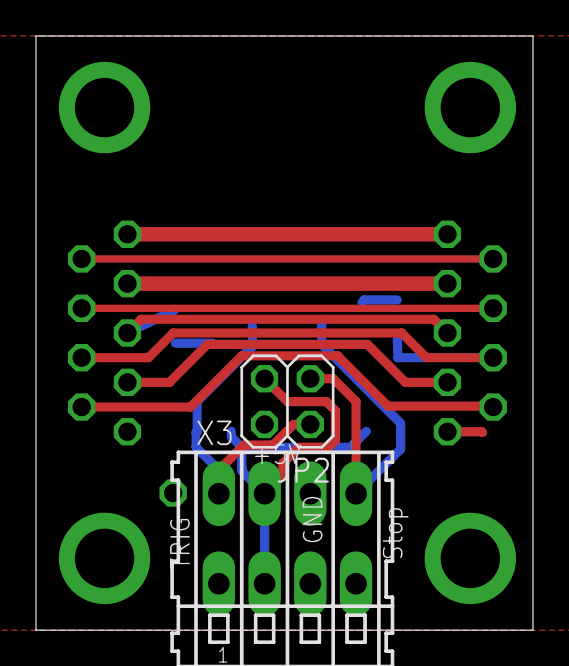
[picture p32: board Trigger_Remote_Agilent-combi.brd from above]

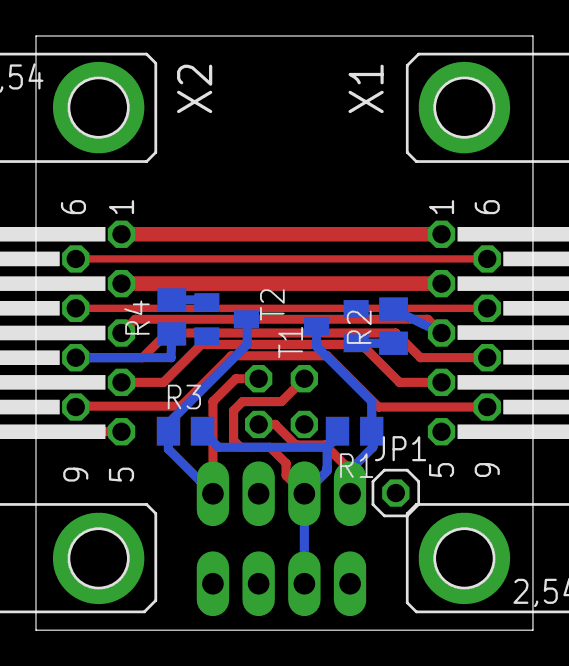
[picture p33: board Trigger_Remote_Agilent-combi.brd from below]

Board: 2 copper layers, 27.6 x 33.0 mm, 11 parts (9 on the bottom side), 14 nets.

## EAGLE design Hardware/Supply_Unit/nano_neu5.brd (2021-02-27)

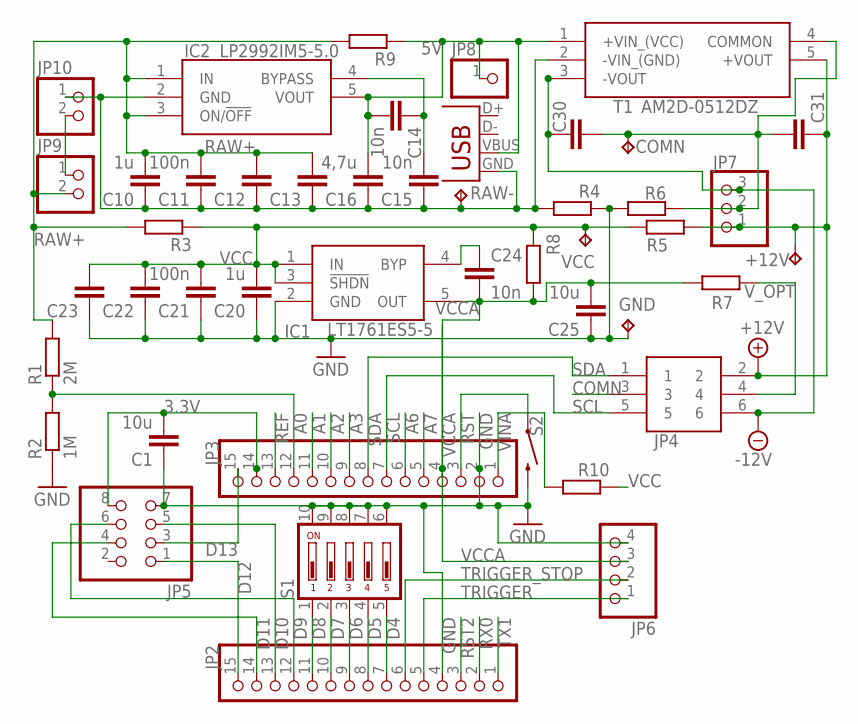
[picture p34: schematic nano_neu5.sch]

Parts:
+12V: TESTPAD_TPTP09SQ; TESTPAD_TP09SQ
C1, C25: 10u; RCL_C0805K
C10, C20: 1u; RCL_C0805K
C11, C21: 100n; RCL_C0805K
C12, C13, C22, C23, C30, C31: RCL_C-EUC1206K; RCL_C1206K
C14, C15, C24: 10n; RCL_C0805K
C16: 4,7u; RCL_C0805K
COMN: TESTPAD_TPTP09SQ; TESTPAD_TP09SQ
GND: TESTPAD_TPTP09SQ; TESTPAD_TP09SQ
IC1: LT1761ES5-5; SAMACSYS_PARTS_SOT95P280X100-5N
IC2: LP2992IM5-5.0; SAMACSYS_PARTS_SOT95P280X145-5N
JP2, JP3: ADAFRUIT_PINHD-1X15-CB; ADAFRUIT_1X15-CB
JP4: SAMACSYS_PARTS_FTSH-103-01-F-D; SAMACSYS_PARTS_FTSH10301FD
JP5: PINHEAD_PINHD-2X4; PINHEAD_2X04
JP6: PINHD-1X4-CB; ADAFRUIT_1X04-CLEANBIG
JP7: ADAFRUIT_PINHD-1X3CB; ADAFRUIT_1X03-CLEANBIG
JP8: PINHEAD_PINHD-1X1; PINHEAD_1X01
JP9, JP10: PINHEAD_PINHD-1X2; PINHEAD_1X02
R1: 2M; RCL_R0805
R2: 1M; RCL_R0805
R3, R4, R5, R6, R7, R8, R9: RCL_R-EU_R0805; RCL_R0805
R10: RCL_R-EU_R0603; RCL_R0603
RAW-: RAW-; TESTPAD_TP09SQ
S1: SWITCH-DIL_219-05; SWITCH-DIL_CTS-219-05
S2: SPARKFUN-SWITCHES_MOMENTARY-SWITCH-SPST-SMD-6.0X3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; SPARKFUN-SWITCHES_TACTILE_SWITCH_SMD_6.0X3.5MM
T1: AM2D-0512DZ; SAMACSYS_PARTS_TMA-0512D
VCC: TESTPAD_TPTP09SQ; TESTPAD_TP09SQ
X1: CON-USB_USB-MB-S

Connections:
3.3V: C1.2, JP3.14, JP5.8
5V: C14.2, C16.2, IC2.5 (VOUT), JP8.1, R9.1, T1.1 (+VIN_(VCC)), X1.VBUS
+12V: +12V.TP, C31.1, JP4.2, JP7.1, R5.2, T1.5 (+VOUT)
-12V: C30.1, JP4.6, JP7.3, T1.3 (-VOUT)
A0: JP3.12, R1.1, R2.2
A1: JP3.11
A2: JP3.10
A3: JP3.9
A6: JP3.6
A7: JP3.5
COMN: C30.2, C31.2, COMN.TP, JP4.3, JP7.2, R6.2, T1.4 (COMMON)
D4: JP2.7, S1.5
D5: JP2.8, S1.4
D6: JP2.9, S1.3
D7: JP2.10, S1.2
D8: JP2.11, S1.1
D9: JP2.12, JP5.6
D10: JP2.13, JP5.5
D11: JP2.14, JP5.4
D12: JP2.15, JP5.1
D13: JP3.15, JP5.3
GND: C1.1, C20.1, C21.1, C22.1, C23.1, C25.1, GND.TP, IC1.2 (GND), JP2.4, JP3.2, JP5.7, JP6.4, R2.1, R4.1, R6.1, S1.6, S1.7, S1.8, S1.9, S1.10, S2.2
unnamed: JP9.1, JP10.2
unnamed: C24.1, IC1.4 (BYP)
unnamed: C14.1, C15.2, IC2.4 (BYPASS)
RAW+: C10.2, C11.2, C12.2, C13.2, IC2.1 (IN), IC2.3 (ON/!OFF), JP9.2, R1.2, R3.2, R9.2
RAW-: C10.1, C11.1, C12.1, C13.1, C15.1, C16.1, IC2.2 (GND), JP10.1, R4.2, RAW-.TP, T1.2 (-VIN_(GND)), X1.GND
REF: JP3.13
RST: JP3.3, S2.1
RST2: JP2.3
RX0: JP2.2
SCL: JP3.7, JP4.5
SDA: JP3.8, JP4.1
TRIGGER: JP2.5, JP6.1
TRIGGER_STOP: JP2.6, JP6.2
TX1: JP2.1
VCC: C20.2, C21.2, C22.2, C23.2, IC1.1 (IN), IC1.3 (!SHDN), R3.1, R5.1, R8.2, R10.1, VCC.TP
VCCA: C24.2, C25.2, IC1.5 (OUT), JP3.4, JP6.3, R7.1, R8.1
VINA: JP3.1, R10.2
V_OPT: JP4.4, R7.2

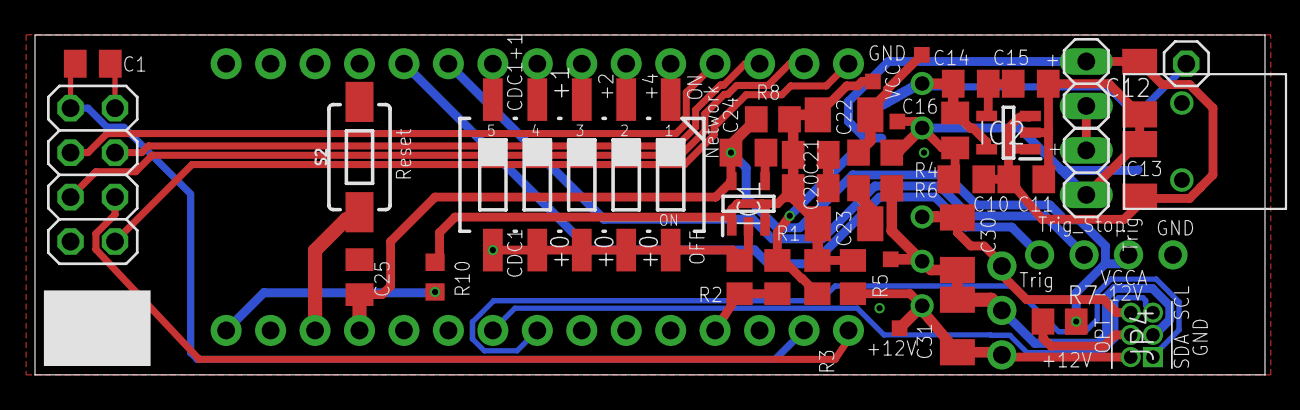
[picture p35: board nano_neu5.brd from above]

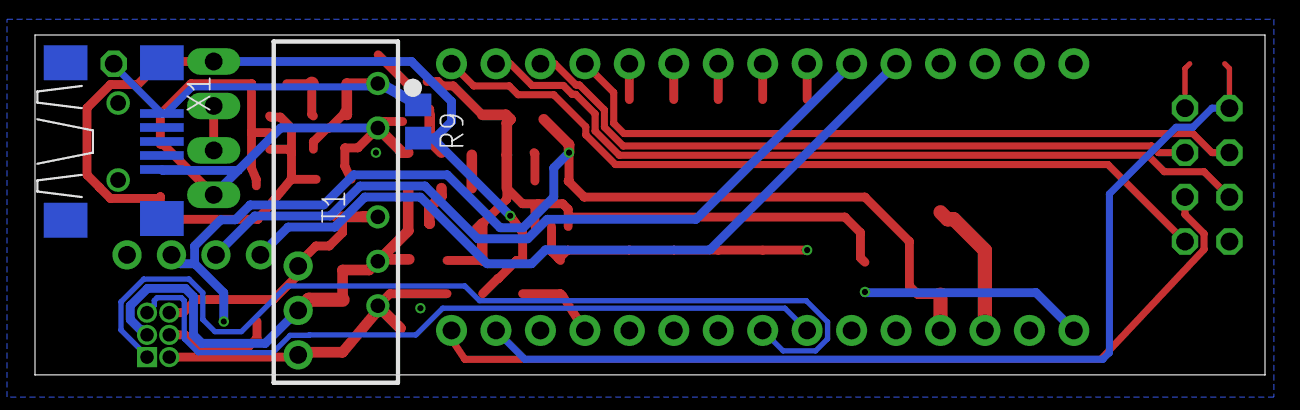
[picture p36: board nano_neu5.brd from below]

Board: 2 copper layers, 70.3 x 19.4 mm, 46 parts (3 on the bottom side), 31 nets.

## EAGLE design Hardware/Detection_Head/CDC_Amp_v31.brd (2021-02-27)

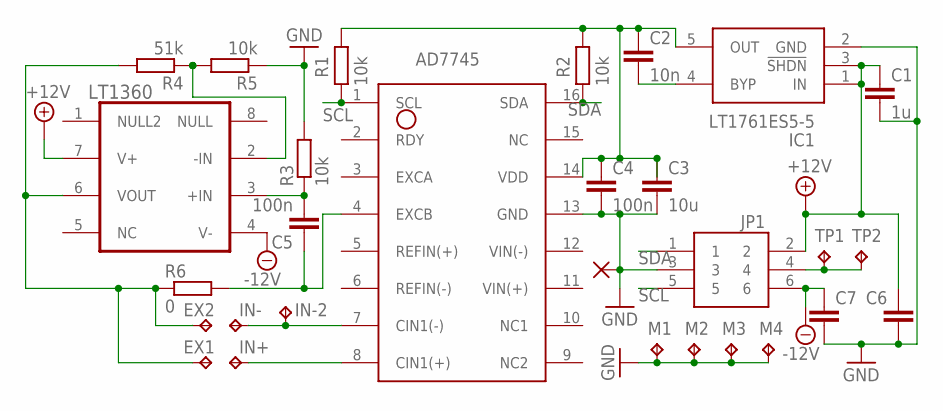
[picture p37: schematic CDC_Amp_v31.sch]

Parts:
AD7745: AD7745; AD7745_TSSOP_16
C1: 1u; RCL_C0805
C2: 10n; RCL_C0805
C3: 10u; RCL_C0805
C4, C5: 100n; RCL_C0805
C6, C7: RCL_C-EUC1206; RCL_C1206
EX1, EX2: TESTPAD_TPTP15R; TESTPAD_TP15R
GND: WIREPAD_1,6/0,8
IC1: LT1761ES5-5; SAMACSYS_PARTS_SOT95P280X100-5N
IN+: TESTPAD_TPTP12R; TESTPAD_TP12R
IN-, IN-2: TESTPAD_TPTP12R; TESTPAD_TP12R
JP1: SAMACSYS_PARTS_FTSH-103-01-F-D; SAMACSYS_PARTS_FTSH10301FD
LT1360: LT1360CS8PBF; SO8
M1, M2, M3, M4: TESTPAD_TPTP15R; TESTPAD_TP15R
R1, R2, R3, R5: 10k; RCL_R0805
R4: 51k; RCL_R0805
R6: 0; RCL_R0603
TP1, TP2: TESTPAD_TPTP08SQ; TESTPAD_TP08SQ

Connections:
+12V: C1.1, C6.1, IC1.1 (IN), IC1.3 (!SHDN), JP1.2, LT1360.7 (V+)
-12V: C7.1, JP1.6, LT1360.4 (V-)
EX_IN: AD7745.4 (EXCB), C5.1, R6.2
EX_OUT: EX1.TP, EX2.TP, LT1360.6 (VOUT), R4.2, R6.1
GND: AD7745.13 (GND), C1.2, C3.2, C4.2, C6.2, C7.2, GND.1, IC1.2 (GND), JP1.3, M1.TP, M2.TP, M3.TP, M4.TP, R3.2, R5.1
unnamed: C5.2, LT1360.3 (+IN), R3.1
unnamed: LT1360.2 (-IN), R4.1, R5.2
unnamed: JP1.4, TP1.TP, TP2.TP
unnamed: C2.2, IC1.4 (BYP)
SCL: AD7745.1 (SCL), JP1.5, R1.1
SDA: AD7745.16 (SDA), JP1.1, R2.1
SIGIN: AD7745.8 (CIN1(+)), IN+.TP
SIGIN-: AD7745.7 (CIN1(-)), IN-.TP, IN-2.TP
V_DD: AD7745.14 (VDD), C2.1, C3.1, C4.1, IC1.5 (OUT), R1.2, R2.2

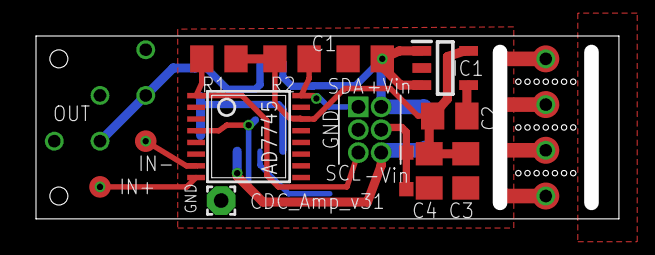
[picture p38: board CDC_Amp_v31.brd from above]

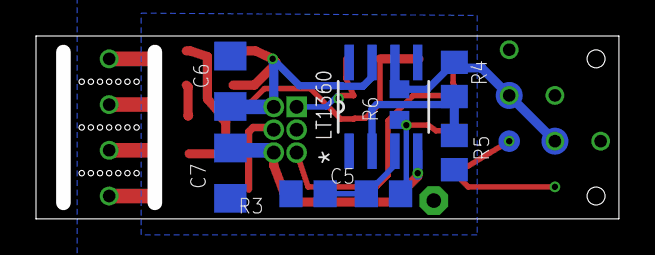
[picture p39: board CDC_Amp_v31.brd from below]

Board: 2 copper layers, 32.4 x 10.2 mm, 29 parts (11 on the bottom side), 14 nets.

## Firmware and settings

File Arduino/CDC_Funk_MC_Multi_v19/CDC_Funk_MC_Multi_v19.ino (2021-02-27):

//Packeges
#include <SBNetwork_config.h>
#include <SBNetwork.h>
#include <Wire.h>
//#include <MemoryFree.h>

// *****Config-Start*****

// Set Network role
bool client = true; // Save bool for client/master
bool ce_ms = !true; //Set Trigger conditions for use with CE-MS (Agilent). require special trigger-board and 4 wire connection
bool onlytrigger = !true; //true, if a dedicated Arduino is used for triggering
bool differential = !true; // Set differential mode
bool temp_on = !true; //toggle for temperatursensor NOT RECOMMENDED
SBNetwork networkDevice(client, 10, 9); // Create a new network device with Arduino and set the _ce and _cs pin. The first argument defines the type of the device. false=master and true=client device

//Trigger config
const byte interruptPin = 2; // Connect intrruptPin via Switch to GND. For use with PRINCE
const byte interruptPinStop = 3;
unsigned long interval_trigger = 5000;    // Interval in ms between two reliable trigger pulses
unsigned long trigbut_reset = 500;  // sets trigbut to 0 trigbut_reset seconds before the next reliable trigger pulses, must be shorter than interval_trigger,
String trigger_tag = String("Tri"); //Identifier for a trigger event

//Config waiting time in ms between reading sensor
unsigned long interval = 10;

//Detector-Identifier
String identifier = String("CDC"); //3 letters for identification;
int cdc_int = 1; //preset for id of CDC, overwritten by switches

//Voltage tracking of supply voltage
const int battary = A0;  // Analog input pin voltage tracking

// Switch for Testing without AD7765 true-> no AD7765
bool debugging = false;
const int analogInPin = A1;  // Analog input pin for Debugging


//////////////////////////////////////////////
//define pins for dip switches (id + Network + ExtraDip) 
#define SelectPinNet 8 //Pin for network toggle
//Pins for id
#define SelectPinA 5 //add 1 to id
#define SelectPinB 6 //add 2 to id 
#define SelectPinC 7 //add 4 to id
//Extra Pin (reserved)
#define ExtraPin 4

/////////////////////////////////////////////


// *****Config-End*****


//Define Values for temp data
String detector = identifier;
bool Network = false;
bool SetupRadio = false;
unsigned long previousMillis = 0; // saves seconds since last change
unsigned long previousMillis_trigger = 0; // saves seconds since last change of trigger
unsigned long previousMillis_trigger_Stop = 0; // saves seconds since last change of stop trigger
unsigned long previousMillis_interrupt = 0; // saves seconds since last interrupt
volatile int trigbut = 0; // saves state of trigger
char det_char[5]; // saves detector identifier in a char
String c_str="";
byte calibration;
byte calibrationB;
int calibrationD;
byte outOfRangeCount = 0;
unsigned long offset = 0; 
long ValueReadFromSensor = 0; //SensorValue
long Temp = 8388608L; //Results in 0 after conversion to C by (X/2048)-4096
int deb_sensorValue = 0; //Value for debugging
long clibNo = 0;
bool last_start = false;
/*

Have option to change between pins 3/7/8 and 4/9/10, since the AD7746 has two capacitance inputs

AD7746 pinout:

Pin 1 SCL
Pin 2 !RDY
Pin 3 EXCA
Pin 4 EXCB
Pin 5 REFIN+
Pin 6 REFIN-
Pin 7 CIN1-
Pin 8 CIN1+
Pin 9 CIN2+
Pin 10 CIN2-
Pin 11 VIN+
Pin 12 VIN-
Pin 13 GND
Pin 14 VDD
Pin 15 NC
Pin 16 SDA
*/
// i2c pins are 4 and 5 for Uno/Nano, 20 and 21 for Mega (SDA/SCL)


/////////////////////////////////////////////////////////////
//AD7746 definitions

#define I2C_ADDRESS  0x48 //0x90 shift one to the right

#define REGISTER_STATUS 0x00
#define REGISTER_CAP_DATA 0x01
#define REGISTER_VT_DATA 0x04
#define REGISTER_CAP_SETUP 0x07
#define REGISTER_VT_SETUP 0x08
#define REGISTER_EXC_SETUP 0x09
#define REGISTER_CONFIGURATION 0x0A
#define REGISTER_CAP_DAC_A 0x0B
#define REGISTER_CAP_DAC_B 0x0C
#define REGISTER_CAP_OFFSET 0x0D
#define REGISTER_CAP_GAIN 0x0F
#define REGISTER_VOLTAGE_GAIN 0x11
#define RESET_ADDRESS 0xBF
#define VALUE_UPPER_BOUND 16777214L 
#define VALUE_ZERO_FARADS 8388607L
#define MAX_OFFSET_ABOVE_ZERO 600000L
#define VALUE_LOWER_BOUND 0xFL
#define MAX_OUT_OF_RANGE_COUNT 3
#define CALIBRATION_INCREASE 1

/////////////////////////////////////////////////////////////
//Configuation Manual for AD7745

//  Capacitive channel setup (REGISTER_CAP_SETUP 0x07)
        // _BV(7)=1 (CAPEN) enables capacitive channel for single conversion, continuous conversion, or calibration
        // _BV(6)=1 (CIN2) switches the internal multiplexer to the second capacitive input on the AD7746.
        // _BV(5)=1 (CAPDIFF) sets differential mode on the selected capacitive input
        // _BV(4) to _BV(1)=0 .
        // _BV(0)=1 (CAPCHOP) The CAPCHOP bit should be set to 0 for the specified capacitive channel performance. CAPCHOP = 1 approximately doubles the capacitive channel conversion times and slightly improves the capacitive channel noise performance for the longest conversion times.

//Voltage/Temperature channel setup (REGISTER_VT_SETUP 0x08)
       // _BV(7) = 1 (VTEN)  enables voltage/temperature channel for single conversion, continuous conversion, or calibration
       // _BV(6) (VTMD1) and _BV(5) (VTMD0) Voltage/temperature channel input configuration. 
          //                                     _BV(6)   _BV(5)    Channel Input 
          //                                     0        0         Internal temperature sensor 
          //                                     0        1         External temperature sensor diode (Transistor 2N3906)
          //                                     1        0         VDD monitor
          //                                     1        1         External voltage input (VIN)
       // _BV(4)=1 (EXTREF) selects an external reference voltage connected to REFIN(+), REFIN(–) for the voltage input or the VDD monitor.
       // _BV(4)=0 selects the on-chip internal reference. The internal reference must be used with the internal temperature sensor for proper operation.
       // _BV(3) an _BV(2)=0
       // _BV(1)=1 (VTSHORT) internally shorts the voltage/temperature channel input for test purposes.
       // _BV(0)=1 (VTCHOP) sets internal chopping on the voltage/temperature channel. The VTCHOP bit must be set to 1 for the specified voltage/temperature channel performance.       

// Configure Excitation (REGISTER_EXC_SETUP 0x09)
        // _BV(7)=1 (CLKCTRL) decreases the excitation signal frequency and the modulator clock frequency by factor of 2.This also increases the conversion time on all channels (capacitive, voltage, and temperature) by a factor of 2.
        // _BV(6)=1 (EXCON) the excitation signal is present on the output during both capacitance and voltage/temperature conversion. Else: the excitation signal is present on the output only during capacitance channel conversion.
        // _BV(5)=1 (EXCB) or _BV(3)=1 (EXCA) enables EXCB or EXCA pin as the excitation output.
        // _BV(4)=1 (EXCB-) or _BV(2)=1 (EXCA-) enables EXCB or EXCA pin as the inverted excitation output.
        // _BV(1) (EXCLVL1) and _BV(0) (EXCLVL0) set Excitation Voltage Level.   _BV(1)=0 and _BV(0)=0 EXC=VDD/2±VDD/8;
        //                                                                       _BV(1)=0 and _BV(0)=1 EXC=VDD/2±VDD/4;
        //                                                                       _BV(1)=1 and _BV(0)=0 EXC=VDD/2±VDD*3/8; 
        //                                                                       _BV(1)=1 and _BV(0)=1 EXC=VDD/2±VDD/2;

//  Converter update rate and mode of operation setup (REGISTER_CONFIGURATION 0x0A)
        // Voltage/temperature channel digital filter setup
          // _BV(7) (VTF1) and _BV(6) (VTF0) Voltage/temperature channel digital filter setup—conversion time/update rate setup. The conversion times in this table are valid for the CLKCTRL = 0 in the EXC SETUP register. The conversion times are longer by a factor of two for the CLKCTRL = 1.
          //                                     _BV(7)   _BV(6)    Conversion Time (ms)  Update Rate (Hz)  ~3dB Freq (Hz)
          //                                     0        0         20.1                  49.8              26.4
          //                                     0        1         32.1                  31.2              15.9
          //                                     1        0         62.1                  16.1              8.0
          //                                     1        1         122.1                 8.2               4.0
        // Capacitive channel digital filter setup
          // _BV(5) (CAPF2) and _BV(4) (CAPF1) and _BV(3) (CAPF0) Capacitive channel digital filter setup—conversion time/update rate setup. The conversion times in this table are valid for the CLKCTRL = 0 in the EXC SETUP register. The conversion times are longer by factor of two for the CLKCTRL = 1.
          //                                     _BV(5)   _BV(4)  _BV(3)    Conversion Time (ms)  Update Rate (Hz)  ~3dB Freq (Hz)
          //                                     0        0        0         11.0                 90.9              87.2
          //                                     0        0        1         11.9                 83.8              79.0
          //                                     0        1        0         20.0                 50.0              43.6
          //                                     0        1        1         38.0                 26.3              21.8
          //                                     1        0        0         62.0                 16.1              13.1
          //                                     1        0        1         77.0                 13.0              10.5
          //                                     1        1        0         92.0                 10.9               8.9
          //                                     1        1        1        109.6                  9.1               8.0
        // Converter mode of operation setup.
          // _BV(2) (MD2) and _BV(1) (MD1) and _BV(0) (MD0)
          //                                     _BV(2)   _BV(1)  _BV(0)    Mode
          //                                     0        0        0        Idle
          //                                     0        0        1        Continuous conversion
          //                                     0        1        0        Single conversion
          //                                     0        1        1        Power-Down
          //                                     1        0        0        -
          //                                     1        0        1        Capacitance system offset calibration
          //                                     1        1        0        Capacitance or voltage system gain calibration
          //                                     1        1        1        -


void setup()
{

  Wire.begin(); // sets up i2c for operation
  Serial.begin(19200); // set up baud rate for serial
  Serial.println("Firmware:CDC_Funk_MC_Multi_v19");
  //Configuration of dip switches for id (3x) and for activating Network
  pinMode(ExtraPin, INPUT_PULLUP);
  pinMode(SelectPinA, INPUT_PULLUP);
  pinMode(SelectPinB, INPUT_PULLUP);
  pinMode(SelectPinC, INPUT_PULLUP);
  pinMode(SelectPinNet, INPUT_PULLUP);
  //SetupRadio = !digitalRead(ExtraPin); // get stat of radio setup switch
  Network = !digitalRead(SelectPinNet); //get state of network by dip switch
  cdc_int = !digitalRead(SelectPinC)*4 +!digitalRead(SelectPinB)*2 + !digitalRead(SelectPinA) + 1;
  if(!client){
    cdc_int = 0;
    Network = true;
    config_notification();
    Serial.println(F("*** PRESS 'E' to handle the switch of adding new clients")); 
  }
  Serial.print("Hello at CDC");
  Serial.println(cdc_int);
  if(!Network and cdc_int != 8){
    SetupRadio = true;
    Serial.println("SetupRadio is active");
    config_notification();
  }
  else if(!Network and cdc_int == 8){
    Serial.println(F("Please make sure that a detector with power supply is connected to configure CDC8 or use a CDC in USB-only mode, in the latter case CDC is always named CDC1"));
    config_notification();
  }
  //activate trigger from interrupt pin
  if(ce_ms){
    pinMode(interruptPin, INPUT);
    pinMode(interruptPinStop, INPUT);
    Serial.println("Agilent Trigger-Mode (4 wire connection)");
  }else{
    pinMode(interruptPin, INPUT_PULLUP);
    pinMode(interruptPinStop, INPUT_PULLUP);
    Serial.println("Prince Trigger-Mode (2 wire connection)");
  }
  attachInterrupt(digitalPinToInterrupt(interruptPin), trigit, CHANGE);
  attachInterrupt(digitalPinToInterrupt(interruptPinStop), trigof, CHANGE);

  // Initialize the network device
  SBMacAddress deviceMac(0x05, 0x04, 0x04, 0x00, 0x00); // Type in here the mac address of the device. This must be unique within your complete network otherwise the network will not work.
  if(Network and !SetupRadio){
    networkDevice.initialize(deviceMac);
    if(!client){
      networkDevice.enableAutomaticClientAdding(false); // Enables the master to automatically add new clients here: disabled
    }
  }

  //cofigure AD7745 
  if(client and !debugging and !onlytrigger and !SetupRadio){
      Serial.print("Init...");
      Wire.beginTransmission(I2C_ADDRESS); // start i2c cycle
      Wire.write(RESET_ADDRESS); // reset the device
      Wire.endTransmission(); // ends i2c cycle
      delay(10);  //wait a tad for reboot (originally 10)
      
      writeRegister(REGISTER_EXC_SETUP, _BV(6) | _BV(5) | _BV(1) | _BV(0)); // EXC source B; Voltage; LOW: 0, HIGH: VDD
            
      if (differential){
        writeRegister(REGISTER_CAP_SETUP,_BV(7) | _BV(5));//enable conversion/calibration and differential Input
      }else{
        writeRegister(REGISTER_CAP_SETUP,_BV(7)); //enable only conversion/calibration
      }
      Serial.println("Get offset");
      offset = ((unsigned long)readInteger(REGISTER_CAP_OFFSET)) << 8;  
      Serial.print("Factory offset: ");
      Serial.println(offset);
      writeRegister(REGISTER_CONFIGURATION, _BV(7) | _BV(6) | _BV(5) | _BV(4) | _BV(3) | _BV(2) | _BV(0));  // set configuration to calib. mode, slow sample (122.1 µs for Time/Volate and 109.6µs for capacitance)
      delay(50); //wait for calibration (originally 10)
      Serial.print("Cal offset1: ");
      offset = ((unsigned long)readInteger(REGISTER_CAP_OFFSET)) << 8;  
      Serial.println(offset);
     
      Wire.beginTransmission(I2C_ADDRESS); // start i2c cycle
      Wire.write(RESET_ADDRESS); // reset the device
      Wire.endTransmission(); // ends i2c cycle
      delay(10);
      //displayStatus();
      Serial.print("Cal offset2: ");
      offset = ((unsigned long)readInteger(REGISTER_CAP_OFFSET)) << 8;  
      Serial.println(offset);
    
       writeRegister(REGISTER_EXC_SETUP, _BV(6) | _BV(5) | _BV(1) | _BV(0)); // EXC source B; Voltage; LOW: 0, HIGH: VDD
            
      if (differential){
        writeRegister(REGISTER_CAP_SETUP,_BV(7) | _BV(5));//enable conversion/calibration and differential Input
      }else{
        writeRegister(REGISTER_CAP_SETUP,_BV(7)); //enable only conversion/calibration
      }
      if (temp_on==true){
        writeRegister(REGISTER_VT_SETUP,_BV(7) | _BV(0));
      }
      writeRegister(REGISTER_CONFIGURATION, _BV(7) | _BV(6) | _BV(5) | _BV(4) | _BV(3) | _BV(0)); // continuous mode; see: Converter update rate and mode of operation setup
      //displayStatus();
      delay(100);
      if (differential){
        delay(10);
        calibrateD(); //determine automatically the offset 
        //writeRegister(REGISTER_CAP_DAC_A, _BV(7) | XX); /Configure Cap-DAC for CIN+, range: 0-127
        //writeRegister(REGISTER_CAP_DAC_B, _BV(7) | XX); /Configure Cap-DAC for CIN-, range: 0-127
      }else{
        calibrate();
      }
      displayStatus();
      Serial.println("done");
  }
  delay(100);
}


void loop() // main program begins
///////////////////////////////////////////////////////////////////////////////////////
{
  while (Serial.available() > 0){ //Configuration over Serial
      char c = toupper(Serial.read());
      c_str +=  c;
      if (c == '\n'){
        if (c_str[0] == 'N' and isdigit(c_str[2])) { //Change bundle number of client with N and bundle number eg: N-4 for bundle 4
          networkDevice.resetData();
          int bu =  c_str[2]-48; //Bad version for converting ASCII-Number to Int
          SBMacAddress deviceMac(0x05, 0x04, 0x04, bu, cdc_int);
          networkDevice.initialize(deviceMac);
          Serial.println("*****");
          Serial.print("Configuration:");
          if(!client){
            Serial.print("Master client-master-set-number:");
          }else{
            Serial.print("Client client-master-set-number:");
          }
          Serial.print(bu);
          Serial.print(" Device-Number: ");
          Serial.println(cdc_int);
          Serial.println("*****");
        }
        if (c_str[0] == 'E') { //Toggle with 'E' AutomaticClientAdding-Function
          // Only master should handle the switch of adding new clients
          if (!networkDevice.RunAsClient) {
            Serial.println("*****");
            if (networkDevice.isAutomaticClientAddingEnabled()) {
              Serial.println("Deactivating AutomaticClientAdding");
            }
            else {
              Serial.println("Activating AutomaticClientAdding");
            }
            Serial.println("*****");
            networkDevice.enableAutomaticClientAdding(!networkDevice.isAutomaticClientAddingEnabled());        
          }
        }
        if (c_str[0] =='S' and client and !onlytrigger){ // 'S' via serial returns settings of CDC
          displayStatus();
        }
        c_str = "";
      }
    }
    
//// Call this in the loop() function to maintain the network device    
  if(Network and !SetupRadio){ 
      networkDevice.update();
    }
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

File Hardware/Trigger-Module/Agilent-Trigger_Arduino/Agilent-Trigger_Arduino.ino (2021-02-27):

const byte interruptPin = 2; // Connect intrruptPin via Switch to GND for PRINCE
const byte interruptPinStop = 3;
unsigned long interval_trigger = 5000;    // Interval in ms between two reliable trigger pulses
int relais[] = {4,6};
unsigned long interval = 1000; //Config puls length has to be shorter than interval_trigger

unsigned long previousMillis = 0; // saves seconds since last change
unsigned long previousMillis_trigger = 0; // saves seconds since last change of trigger
unsigned long previousMillis_trigger_Stop = 0; // saves seconds since last change of stop trigger
volatile int trigbut = 0; // saves state of trigger
bool aktiv = false;
bool last_start = false;

void setup()
{
  Serial.begin(19200); // set up baud rate for serial
  Serial.println("Hello eDAQ-Trigger_Duo3");
  pinMode(interruptPin, INPUT);
  pinMode(interruptPinStop, INPUT);
  attachInterrupt(digitalPinToInterrupt(interruptPin), trigit, CHANGE);
  attachInterrupt(digitalPinToInterrupt(interruptPinStop), trigof, CHANGE);
  for(int i=0; i < 2; i++){
    pinMode(relais[i], OUTPUT);
    digitalWrite(relais[i], HIGH);
    Serial.println(i);
  }
}


void loop() // main program begins
///////////////////////////////////////////////////////////////////////////////////////
{
    
//Trigger
  if ((millis() - previousMillis_trigger > interval_trigger) && trigbut == 1) {
    Serial.println("ON_Start");
    for(int i=0; i < 2; i++){
      digitalWrite(relais[i], LOW);
    }
    previousMillis_trigger = millis();  //save current time
    previousMillis = millis();
    aktiv = true;
    last_start = true;
  }
  if ((millis() - previousMillis_trigger_Stop > interval_trigger) && trigbut == 2 && last_start == true) {
    previousMillis_trigger_Stop = millis();  //save current time
    previousMillis = millis();
    Serial.println("ON_Stop");
    for(int i=0; i < 2; i++){
      digitalWrite(relais[i], LOW);
    }
    aktiv = true;
    last_start = false;
  }
  if (trigbut == 2 && last_start == false) {
    Serial.println("nth Stop cancled");
    trigbut = 0;
  }
  if (aktiv && (millis() - previousMillis > interval)){
    Serial.println("OFF");
    for(int i=0; i < 2; i++)
    {
      digitalWrite(relais[i], HIGH);
    }
    aktiv = false;
    trigbut = 0;
  }
}


void trigit() {
  //if (trigbut == 0){
    trigbut = 1;
    Serial.println("go ");
  //}
}

void trigof() {
  //if (trigbut == 0){
    trigbut = 2;
    Serial.println("STOP ");
  //}
}

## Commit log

2021-02-27 First Upload
    [CDC_Amp_v31.brd, CDC_Amp_v31.sch, Calibration_Voltage.xlsx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]
2021-02-27 Trigger modified
    [Trigger.kicad_pcb, Trigger.sch]
2021-02-27 Frist upload
    [Parts.xlsx, Trigger_Remote_Agilent-combi.brd]
